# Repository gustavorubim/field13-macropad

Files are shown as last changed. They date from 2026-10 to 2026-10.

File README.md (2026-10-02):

# FIELD 13

An original, editable DIY macropad prototype with 13 MX hot-swap keys, a rotary encoder, a two-axis joystick, an optional touch position and a soldered Raspberry Pi Pico W.

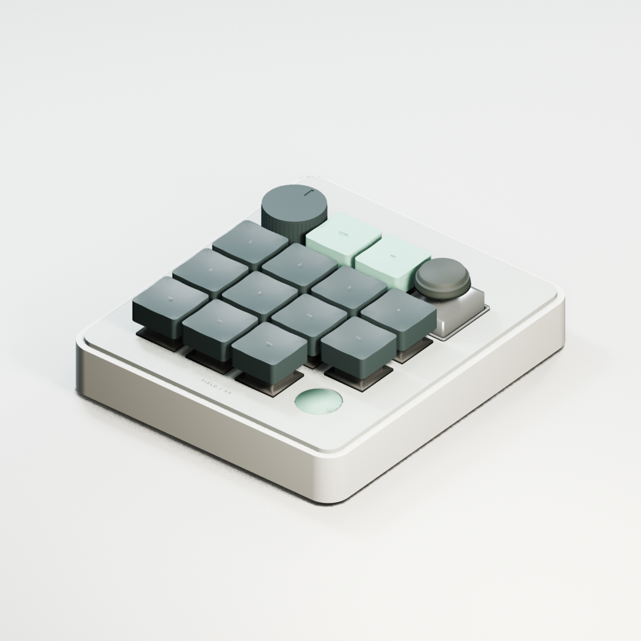
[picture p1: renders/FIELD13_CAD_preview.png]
FIELD 13 CAD assembly


**A0 design prototype. Not yet a fabrication release.** The files are real CAD, PCB and source code, but there has been no physical assembly, electrical bring-up, radio test or print-fit test. Software checks and CAD clearances cannot replace those tests.

## What is here

| Area | Deliverable |
|---|---|
| Electronics | Editable KiCad schematic, two-layer routed board, custom symbol/footprint libraries, source links and check reports |
| Mechanical | Native FreeCAD full assembly, STEP, printable case/plate/knob/feet, fit coupon and reproducible parameters |
| Visuals | Direct CAD preview, studio front/top/rear views, exploded view and editable Blender studio scene |
| Firmware | Code-configured keymaps/layers, encoder/media controls, joystick arrows/mouse, USB HID, optional authenticated Windows Wi-Fi companion |
| Integration | Optional Microbridge local serial companion for six agent focus keys and LED feedback; macOS daemon baseline |
| Build | Exact-part BOM, pin map, assembly instructions, bench tests and explicit remaining validation gates |

The layout follows the requested control arrangement: encoder and joystick around two top keys, two rows of four keys, and three bottom keys next to the optional touch position. All keycaps are standard 1U. The enclosure is 108 × 122 mm, with rounded corners, rear port access, underside fasteners and TPU feet.

## Start here

1. Read [the current verification status](docs/verification.md)
2. Inspect the KiCad project in `electronics/` and [electrical notes](docs/electronics.md)
3. Review [mechanical dimensions and print-fit gates](docs/mechanical.md)
4. Use the [BOM](docs/BOM.csv) and [assembly guide](docs/assembly.md)
5. Configure [firmware and host companions](docs/firmware.md)

## Editable sources

- `electronics/macropad.kicad_sch` and the final routed `.kicad_pcb` named in the electrical notes
- `mechanical/FIELD13_assembly.FCStd` and `FIELD13_assembly.step`
- `mechanical/parameters.json` plus `scripts/generate_mechanical.py`
- `mechanical/stl/` for printable parts, including the fit coupon
- `mechanical/FIELD13_studio.blend` plus `scripts/render_blender.py`
- `firmware/config.py` for keymaps, layers, encoder direction, joystick calibration and transport

The FreeCAD document has named editable solids, design-profile sketches and a dimension reference sheet. Regenerate changed dimensions from the JSON rather than assuming that changing the displayed sheet rebuilds the BRep solids. Purchased parts use documented clearance envelopes; not every small SMT detail is reproduced in CAD.

## Connectivity limits

USB HID is the default. Pico W Wi-Fi mode uses a separately started Windows companion and explicitly configured pairing key. It is not Bluetooth HID. CircuitPython's Pico W target does not provide CYW43 BLE HID in this build. No credentials are included, and no host service installs itself.

The optional Microbridge adapter is separate from the Windows Wi-Fi companion. It targets the pinned upstream protocol and only focuses/open assigned agent slots and receives status colors. It does not impersonate the commercial device's USB identity, approve actions, reject requests or synthesize unsupported daemon controls.

Power is USB or a finished external USB power bank. There is no bare lithium cell, charger or unprotected battery circuit. The microphone is a reserved connector/bay, not a tested microphone or USB-audio implementation. Optional touch/RGB peripherals require their own physical validation.

## Gallery

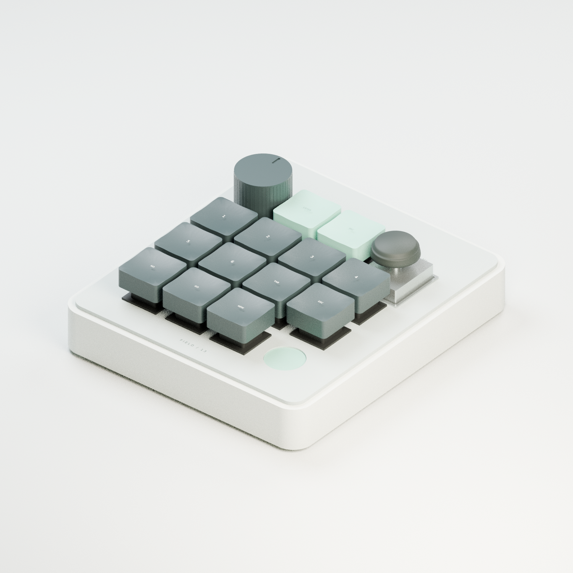
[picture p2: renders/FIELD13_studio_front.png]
Studio front

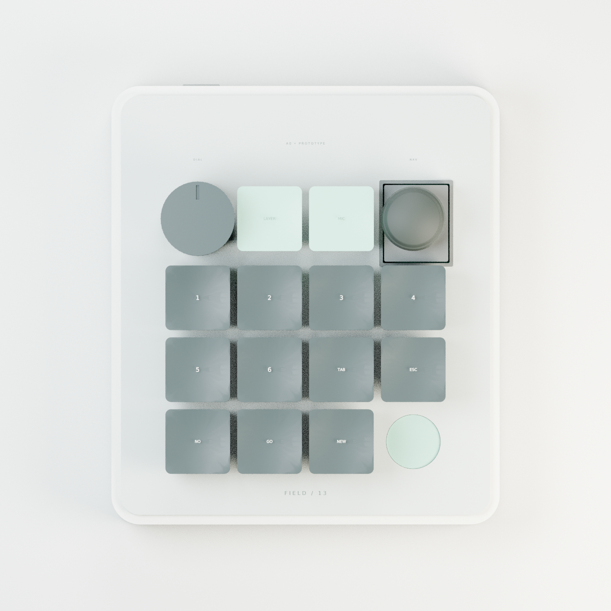
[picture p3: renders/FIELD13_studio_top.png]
Top view

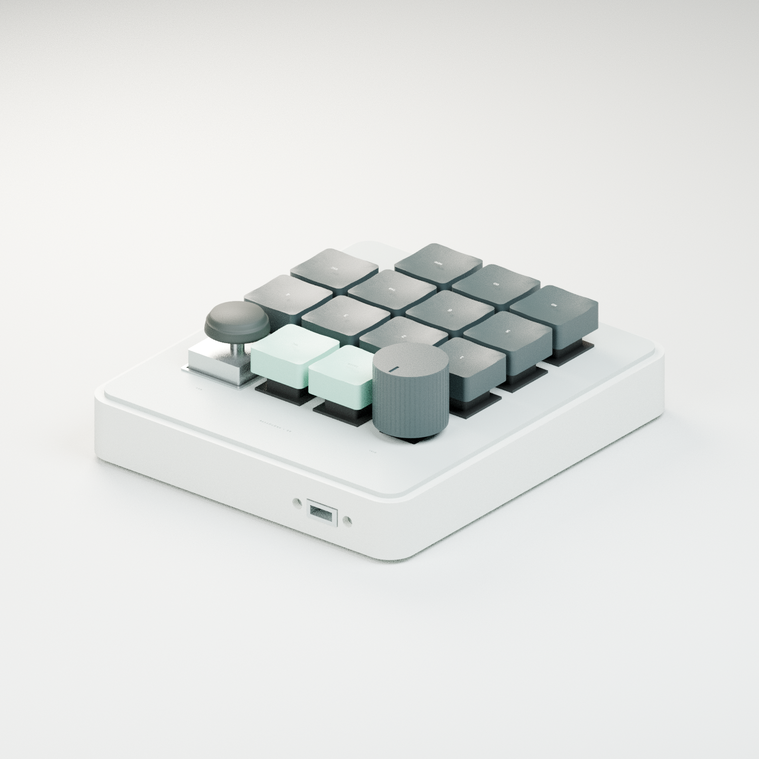
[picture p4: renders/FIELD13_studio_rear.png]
Rear view

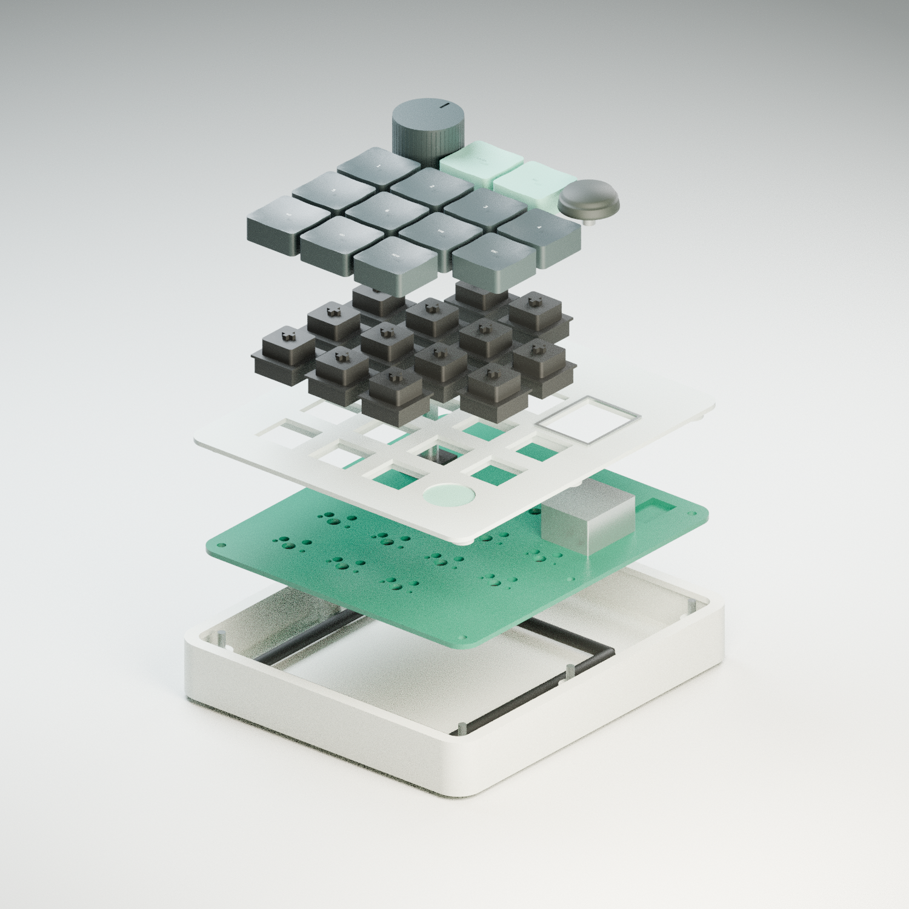
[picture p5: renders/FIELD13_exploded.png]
Exploded assembly


## Reproduce checks

```sh
python -m unittest discover -s tests/firmware -v
python -m compileall -q firmware
/usr/bin/python3 scripts/generate_mechanical.py
HOME=/tmp/macropad-home kicad-cli sch erc electronics/macropad.kicad_sch
```

The electrical notes identify the final PCB, final ERC/DRC commands and report files. Generated file paths are relative to this repository except where a tool requires its system library path. KiCad 9.0.2, FreeCAD 1.0 and Blender 4.3.2 were used in the development VM.

## Sources and credit

The requested arrangement was inspired by [OpenAI Supply Co. × Work Louder](https://openai.com/supply/co-lab/work-louder/). FIELD 13 is an independent DIY design, not an official product, clone firmware, compatibility certification or endorsement.

Component geometry and electrical constraints are based on the manufacturer sources linked in the BOM and electrical notes. Optional Microbridge interoperability is pinned to [DevVig/microbridge, fcd0aba](https://github.com/DevVig/microbridge/tree/fcd0aba7a4fa360ca8690681bd7b049fa3682f10). Third-party datasheets and external executable tools are not republished in this repository.

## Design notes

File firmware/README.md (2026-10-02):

# FIELD13 firmware prototype

Start with [the complete setup and verification guide](../docs/firmware.md).

- `boot.py`, `code.py`, `config.py`, `macropad/`: copy to CIRCUITPY
- `diagnostics.py`: optional non-HID hardware calibration tool
- `settings.example.toml`: placeholders only; Wi-Fi is opt-in
- `companion/wifi_companion.py`: Windows authenticated Wi-Fi HID, dry-run by default
- `companion/microbridge_companion.py`: macOS/Linux USB serial → local Microbridge v0, focus/LED only

USB is the default. No software or services are installed automatically. Real
CircuitPython, GPIO, USB enumeration, Windows input injection and radio operation
have **not** been tested on physical hardware. This is prototype source, not a
factory-ready binary or Bluetooth firmware.

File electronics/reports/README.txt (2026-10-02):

CANONICAL FINAL REPORTS: DRC.rpt and DRC.json (all severities plus schematic parity), ERC.rpt and ERC.json. All show zero violations. pcb_connectivity_check.json verifies 137 pin mappings against the electrical manifest. final_sha256.json binds these reports to the saved design. history/ contains superseded intermediate reports and is not the final status.

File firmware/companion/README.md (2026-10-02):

# Optional host companions

Both programs use Python 3's standard library and run in the foreground. Neither
is installed or started by this package. See `../../docs/firmware.md` for pairing,
security boundaries, firmware setup and full bring-up procedure.

## Windows wireless keyboard / mouse

```powershell
# Set ARC13_PSK privately in this process, identical to Pico settings.toml.
# Keep the whole firmware folder so the receiver imports the same config.py.
python firmware/companion/wifi_companion.py --bind 192.168.1.10 --device 192.168.1.20
# Inspect dry-run reports first. Only then explicitly enable OS input:
python firmware/companion/wifi_companion.py --bind 192.168.1.10 --device 192.168.1.20 --enable-input
```

Bind exact trusted-LAN IPv4s; reserve Pico DHCP address. Restrict inbound UDP
41413 to that device in the firewall yourself. Do not expose this port to the
Internet. Authenticated HMAC-SHA256 packets are **not encrypted**. No remote shell,
text command execution, arbitrary hotkey API, or Microbridge routing is provided.
Actual Windows SendInput operation is hardware/OS-untested.

## macOS Microbridge focus and LED mirror

```sh
python3 firmware/companion/microbridge_companion.py \
  --port /dev/cu.usbmodemYOUR_DATA_PORT \
  --socket "$HOME/.microbridge/microbridged.sock"
```

Choose the Pico's **data** CDC port, not its REPL console. No USB VID/PID scanning
or impersonation is used. On Linux the TTY commonly resembles `/dev/ttyACM1`,
but identify it rather than assuming an index. The local daemon must already be
installed and running; this package does not install it or change adapter consent.

Pin inspected: `DevVig/microbridge@fcd0aba7a4fa360ca8690681bd7b049fa3682f10`
(v0.3.10 formula commit). Exact sources:

- [Protocol](https://github.com/DevVig/microbridge/blob/fcd0aba7a4fa360ca8690681bd7b049fa3682f10/docs/protocol.md)
- [Rust message types](https://github.com/DevVig/microbridge/blob/fcd0aba7a4fa360ca8690681bd7b049fa3682f10/crates/mb-protocol/src/lib.rs)
- [Daemon handshake and subscribe implementation](https://github.com/DevVig/microbridge/blob/fcd0aba7a4fa360ca8690681bd7b049fa3682f10/crates/microbridged/src/socket.rs)

Only UI-role `hello` (protocol 0), `subscribe`, and `activate_agent_key` (indices
0–5, `open:true`) go to the daemon. Opening depends on the owning adapter's
`focus_open` capability. No `approve`, `reject`, interrupt, command passthrough,
or encoder injection is present. This is a narrow UI-protocol bridge, not an
upstream custom `Device` implementation and not the full Microbridge hardware.

`snapshot.agent_key_led_frame` and
`event.led_frame` (`kind=agent_keys_changed`) supply six static RGB colors.
Upstream percent brightness and pause are respected; the Pico adds its own local
power cap. Focus/breathing animations are not reproduced. Missing or incompatible
frames fail dark. The companion refreshes its snapshot every two seconds, treats
six seconds without a valid frame as stale, and sends LEDs every 0.5 seconds.
The Pico independently blacks out after two seconds without a valid LED message.

Fragmentation and **all** messages in a serial read are parsed. A bounded FIFO
preserves activation order at five per second, expiring queued input after two
seconds and socket write commands after 0.5 seconds. Disconnection discards
queued activations. This rate cap is intentionally for six agent focus buttons,
not a general keyboard input stream.

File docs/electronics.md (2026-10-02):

# FIELD 13 carrier electronics revision A

Engineering prototype, not a fabrication release. The supplied PCB is a real editable two-layer KiCad design with connected nets, routed copper, plated vias, manufacturer-derived footprints and an antenna cutout. Electrical and physical review gates are distinct: an ERC/DRC pass does not certify the new footprints, RF performance, USB budget, or printed assembly fit.

## Verification snapshot

The final KiCad 9 check includes all severities and schematic parity. `reports/DRC.rpt` and `DRC.json` report 0 violations, 0 unconnected pads and 0 footprint/parity errors under 0.20 mm trace/clearance and 0.50 mm edge rules. `reports/ERC.rpt` and `ERC.json` report 0 violations. The exported netlist was independently compared against all 137 electrical pin mappings. Physical review gates below remain open.

## Open and inspect

Open `electronics/macropad.kicad_pro` in KiCad 9. The main schematic is `macropad.kicad_sch`; the final PCB is `macropad.kicad_pcb`. Project-local symbol and footprint libraries are included. `net_manifest.json` gives the exact component/pin/net contract. `exports/` contains schematic SVG, PNG, PDF and native/XML netlists. `previews/` contains PCB top and mirrored-bottom SVG/PNG. `reports/` contains unfiltered KiCad checks and independent connectivity validation. Manufacturer sources are linked in the BOM; downloaded third-party datasheets are not republished in the repository.

Build scripts are editable. Do not run `build_pcb.py` over an edited PCB: it recreates placement and initial escape tracks; the full routing workflow is described below. The schematic generator also recreates its outputs.

## Geometry and assembly

- Case datum: rear is y=0, front y=122, width 108 mm
- Carrier: x 4..104, y 3.5..116, R6 corners, 1.6 mm thickness, PCB top Z 13.6 and bottom Z 12
- Six unplated Ø2.7 M2.5 clearance holes at (9,9), (99,9), (9,63), (99,63), (9,111), (99,111)
- Key centers: top (44,37),(64,37); rows x 24,44,64,84 at y 59 and 79; bottom x 24,44,64 at y 99
- Encoder shaft center (24,37); bare joystick shaft center (84,37)
- Optional vertical headers J1/J2/J3 are DNP and do not fit the closed case: their pin height exceeds the 3.6 mm PCB-to-plate gap. Use direct-solder insulated wire pigtails to the same pads for fitted options; validate strain relief and cable clearance
- Touch connector J1 runs horizontally from x 91 to 98.62 at y 94; it is a connector for an optional external module, not an onboard touch sensor
- RGB J2 at x 19..24.08,y 15; mic J3 at x 20..32.7,y 23; these and the encoder/joystick are front-side parts
- All 13 hot-swap sockets and diodes, Pico W, RGB buffer and passive parts are on the back
- Optional C2 is a 5.8 mm-tall underside part. It is DNP by default; do not assume the 4 mm socket clearance is sufficient for it

### Pico W mounting and RF

Pico W body outline is x 42..93,y 5..26. USB faces left, antenna right. Solder its castellations directly to carrier bottom pads with its components facing away from the carrier. No plug-in header stack is used. A real 14×9 mm carrier cutout is x 84..93,y 8.5..22.5. Copper rules prevent routing through the antenna window/end region. The underside interior beneath the module is also kept free of copper to avoid shorting exposed module testpoints. Four Ø2 mm unplated relief holes beneath USB shell solder joints reduce the risk of solder bulges holding the module off the carrier.

The rear board edge was extended 0.5 mm from y 4 to y 3.5, retaining R6 corners, to preserve a 0.5 mm copper-to-edge rule beneath the Pico pad row. Two vias near the antenna cutout were moved to y 7.68, with adjacent tracks rechecked.

A minimum mechanical no-metal volume of x 81..96,y 5.5..25.5 is reserved around the antenna. The module's own required castellated pads occupy the flanking rails; the carrier does not add a ground fill there. The right-rear nonmetallic printed boss has a 3.4 mm radius to support the heat-set insert. Its plastic enters the added 3 mm allowance by 0.4 mm; the brass insert (2.1 mm radius) and screw head (2.5 mm radius) stay outside the no-metal region. This nearby plastic is another reason RF performance must be measured. The enclosure is plain polymer near the antenna. This remains an interior-antenna arrangement; Raspberry Pi recommends board-edge placement. Measure wireless range with the final case and compare against a bare Pico W before accepting the arrangement. Avoid conductive filament, metalized paint, a battery, or bundled USB cable in this volume.

Raspberry Pi's datasheet explicitly specifies the 14×9 mm cutout and warns that nearby objects in any dimension reduce antenna effectiveness. The extra 3 mm margin is this prototype's engineering allowance, not a manufacturer guarantee. See the [Pico W datasheet](https://datasheets.raspberrypi.com/picow/pico-w-datasheet.pdf), mechanical section 2.2.1.

### Switch sockets

Kailh CPG151101S11-16 uses two Ø3 mm socket openings, 6.35 mm horizontal and 2.54 mm vertical separation. Custom pads are 2.55×2.5 mm at (-7.385,-2.54) and (6.115,-5.08) relative to key center. Stem hole Ø4 mm; optional five-pin switch locating holes Ø1.7 at x±5.08. Socket pads are on B.Cu. The pads were derived from the [manufacturer drawing](https://www.kailhswitch.com/Content/upload/pdf/202215927/CPG151101S11-16.pdf), matching the supplied earlier prototype reference. Print a footprint/plate coupon and physically insert the actual socket and switch before ordering a full carrier. No manufacturer's solderability or tolerance certification is claimed.

### Encoder

Chosen exact part is [ALPS EC11E15244B2](https://tech.alpsalpine.com/e/products/detail/EC11E15244B2/), 15 pulses, 30 detents, push travel 1.5 mm. Its current catalog uses Drawing 3. PCB mounting plane to tip is 24.5 mm, so the bare tip is Z 38.1 mm; the advertised 20 mm actuator dimension starts at the front of the 4.5 mm-thick encoder body. Shaft Ø6 with 4.5 mm flat dimension; the D-flat extends 10 mm down from the tip. Front body envelope is approximately 11.7×12 mm. The selected footprint is KiCad's EC11E vertical H20 switch footprint, with shaft center offset (7.5,2.5) from its pad-A origin. Verify its mounting tabs and slots against the purchased lot and current manufacturer drawing before fabrication.

### Joystick

Chosen exact part is [ALPS RKJXV1224005](https://tech.alpsalpine.com/e/products/detail/RKJXV1224005/), two 10 k linear pots and push switch. Its body is 17.8×21.3×11.2 mm; bare shaft reaches 18.95 mm above PCB, so tip Z 32.55. Boss projects 0.75 mm below its mounting plane, motion ±23°. The manufacturer's mounting-side diagram is saved next to the dimensional drawing. Pot terminals are at y=-8.73 with x=-2.5,0,2.5 and at x=8.73 with y=-2.5,0,2.5. Switch terminals are at x±4.3,y 0. Manufacturer-prohibited front-side wiring regions are covered conservatively by copper keepouts.

The F.Fab body outline uses approximately x−8.1..+9.7,y−9.4..+11.9 relative to shaft, interpreted from the manufacturer drawing scale. The 17.8×21.3 overall size is dimensioned, but these asymmetric shaft-to-body offsets are not independently dimensioned. They are explicitly provisional; the mechanical aperture includes extra allowance and requires a physical coupon.

This part is officially Not Recommended for New Designs. The exact part was offered by LCSC at the dated BOM check; availability can change. RKJXV122400R is not silently substituted: it has a different stated 18.2×21.7 mm envelope and must be reviewed as a distinct part. The custom joystick footprint, mounting tab drills, and shaft cap fit are first-article review gates.

## Electrical contract

| Function | Pico GPIO | Physical pins / notes |
|---|---|---|
| Rows 0..3 | GP0,1,2,3 | 1,2,4,5; drive one row low |
| Columns 0..3 | GP4,5,6,7 | 6,7,9,10; pull-up inputs |
| Encoder A/B/click | GP8,9,10 | 11,12,14; common and click return GND |
| Joystick click | GP11 | 15; active low |
| Optional touch SDA/SCL | GP12,13 | 16,17; I2C0; 3.3 V only |
| Optional six-pixel RGB | GP15 | 20; TTL-input AHCT buffer shifts to 5 V |
| Optional I²S BCLK/WS/DATA | GP16,17,18 | 21,22,24; reserved connector |
| Joystick X/Y | GP26,27 | 31,32; ADC0/1 |

The matrix positions are r0c1–r0c2; r1c0–r1c3; r2c0–r2c3; r3c0–r3c2. Each electrical path is COL → switch → diode anode → diode cathode → ROW. D1–D13 pin 1 is cathode. Firmware must scan columns with pull-ups while sinking one selected row. Never drive a column high against a selected low row through a pressed key.

Joystick pots are powered from 3V3, not 5 V. Direction and neutral deadband need calibration using the assembled joystick. Mechanical encoder contacts use GPIO pull-ups and firmware debounce; no 5 V signals go directly to Pico GPIO.

U2 is SN74AHCT1G125DBVR powered from USB 5 V, /OE grounded, with 100 nF bypass. Its input uses a 10 k pull-down, output a 330Ω series resistor. J2 pin 1=5V_USB,pin 2=RGB_DOUT,pin 3=GND. This is a low-speed pixel output, not a bidirectional 3.3 V expansion pin.

J1 pin 1=3V3,2=GND,3=SDA,4=SCL; optional 4.7 k pull-ups R1/R2 are DNP if a chosen module already supplies them. J3 pin 1=3V3,2=GND,3=BCLK,4=WS,5=DATA,6=GND. A microphone module must be a compatible 3.3 V I²S device; no microphone is fitted in this carrier revision.

## Power limits

The baseline is USB-only through the Pico W micro-B connector and the selected Adafruit 3258 panel extension. There is no lithium charging, protection, boost stage, battery connector, or battery firmware here. A finished external USB power bank may be used only as a 5 V USB source.

Do not allow six pixels at unrestricted full-white current. Start with all RGB off; target a conservative total pixel budget of 60 mA, then measure total USB draw with wireless transmitting and all options fitted. Confirm USB enumeration/descriptors and available host current. The optional 100 uF C2 is DNP until USB inrush is measured and accepted. Neither successful routing nor ERC measures power consumption or USB compliance.

## PCB manufacture and validation gates

The carrier uses two copper layers, nominal 0.25 mm signal routes, local 0.20 mm finished neckdowns, 0.20 mm clearance, 0.60 mm vias with 0.30 mm drills, and 0.50 mm copper-to-edge minimum. No ground pours were added; ground is explicitly routed. Confirm these limits with the intended fabricator and review current return paths, especially RGB current and ADC noise. This is a conservative first functional prototype, not an RF-optimized layout.

Before an order: read the final DRC report, inspect routed previews, confirm every custom footprint on a 1:1 print against physical parts, inspect the cutout and four USB relief holes, verify case ribs and component underside heights, and obtain a second PCB review. Before full assembly: print the mechanical fit coupon, test the matrix and controls on the bench, check supply polarity and USB draw, then assemble the case and repeat RF/joystick sweep tests.

## Reproducible routing

`build_pcb.py` uses system KiCad 9 pcbnew to create project footprints, placement, keepouts, and initial escapes, then writes Specctra `macropad.dsn`. The supplied routed PCB was made with official Freerouting 2.4.1 headless, followed by `finish_routes.py` to close two remaining connections against actual obstacles and KiCad DRC. Freerouting sources/release: https://github.com/freerouting/freerouting/releases/tag/v2.4.1 . The downloaded runtime is a temporary build tool, not included or installed on the user's computer.

The final PCB must be treated as authoritative. Re-running placement alone destroys its routing. The source scripts and final check reports preserve the reproducible design logic and verification evidence. Temporary `.dsn`, `.ses`, router executables and raw logs are excluded from the published repository; they are regenerated during a fresh routing run. Router-local 'violations' are not presented as KiCad results; the final KiCad report is the relevant geometric check. All reported physical manufacturing limits still require a first-article review.

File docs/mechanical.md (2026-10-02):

# FIELD 13 — mechanical prototype A0

The assembly is original and inspired by the reference control arrangement. It does not copy the original product's dimensions, industrial design files, marks, or electronics.

## Files and editability

- `mechanical/FIELD13_assembly.FCStd`: native FreeCAD document, individual named BRep solids, dimensions sheet, and separately editable design-profile sketches
- `mechanical/FIELD13_assembly.step`: complete neutral CAD assembly
- `mechanical/stl/`: printable parts and fit coupon, each shifted onto Z=0
- `mechanical/parameters.json`: the authoritative mechanical parameters; edit and run `/usr/bin/python3 scripts/generate_mechanical.py` to regenerate all manufacturing files
- `mechanical/FIELD13_studio.blend`: studio scene built from the same exported assembly geometry

The named BRep components can be inspected and modified with ordinary FreeCAD modeling tools. Changing the displayed dimensions sheet alone does not regenerate the BRep components; use the JSON and generator. Purchased-part geometry is a clearance envelope, not the manufacturer's full manufacturing model.

## Stack and fit

| Item | Dimension |
|---|---:|
| Case footprint | 108 × 122 mm |
| Outside corner radius | 8 mm |
| Base floor / nominal walls | 2.4 / 2.4 mm |
| Main PCB underside / top | 12.0 / 13.6 mm |
| Switch-plate underside / top | 17.2 / 18.7 mm |
| MX plate thickness at retention clips | 1.5 mm |
| PCB top → plate top | 5.1 mm |
| Key center pitch | 20 mm (top→middle 22 mm) |
| Initial switch cutout | 14.1 × 14.1 mm |
| Plate-to-case radial gap | 0.25 mm |
| Fasteners | six underside M2.5 screws |

The switch plate has reinforcement webs between rows and columns. Diodes and hot-swap sockets belong below the PCB. Push an MX switch fully into the plate before fitting its pins into a socket; support the socket from below during insertion. Hot-swap describes future switch replacement, not a solderless assembly process: every socket is soldered to the carrier PCB.

## Materials and first print

The user's stated GF-ABS, PETG and TPU options are retained; no printer or nozzle is assumed. Use GF-ABS or PETG for the rigid case, plain PETG for the RF-adjacent region and touch cover if necessary, and TPU for feet/joystick cap. Carbon-filled material is not treated as a substitute for glass-filled material near the antenna. RF behavior needs a real assembled test.

Print both the switch/shaft and control-aperture fit coupons first using the actual printer, nozzle and material. It includes 13.9/14.1/14.3 mm switch apertures and 6.0/6.2/6.4 mm shaft bores. The control coupon contains the encoder body opening and conservative joystick aperture. The joystick’s 17.8 × 21.3 mm overall body is manufacturer-documented, but its asymmetric offset about the shaft was estimated from the drawing; this requires a received-part fit test. Adjust clearances before a full print. Use the filament maker's temperature/drying settings; for abrasive filled materials, use the nozzle manufacturer’s suitable wear-resistant hardware. No slicer profile is certified here.

Base: floor on bed. Plate: flat upper surface down, bosses/ribs up; no supports inside switch openings. Knob: top on bed if the cosmetic surface permits. Feet: flat on bed in TPU. Check whether your slicer creates disconnected islands and rejects any non-manifold mesh before printing.

## Retention, wiring and service

The six mounts clamp the PCB between the base standoffs and upper plate bosses. Brass inserts are installed into the underside of the plate. Use the specified short insert variant; a longer insert can break through the visible face. Heat and hole fit must be calibrated with the actual plastic. The selected Accu SPP-M2.5-16-ST-BZP DIN 7985Z screw has a 5 mm maximum head diameter and 2.12 mm maximum head height. The 5.4 mm pocket is 1.7 mm deep, so the head may project 0.42 mm below the base, still above the 1.7 mm feet. Confirm this in a dry assembly before purchasing a full batch.

The rear port uses Adafruit 3258, a micro-B extension with 17.3 mm mounting-ear pitch. The port opening and body envelope still require measurement of the received cable. Its excess length routes in the floor corridor, secured by the two tie saddles, without loading the Pico USB connector. Do not substitute a power-only cable. The superficially convenient Adafruit 4056 USB-C adapter is deliberately not the baseline because its manufacturer warns of missing Type-C negotiation resistors.

Pico W is directly soldered to the underside carrier pads, with components facing the base. The antenna has the official 14 × 9 mm carrier cutout plus a larger no-copper/no-metal area. The module remains interior-mounted in this compact prototype. Antenna performance and interference are not established by a CAD check.

## Optional features

The touch position is a replaceable dielectric disc. The electrode/controller is optional and must be tested through the selected cover thickness. The optional vertical headers do not fit beneath the closed plate as drawn. Use direct-solder insulated wire pigtails at the same pads for a closed-case prototype; do not populate the listed vertical header variants without redesigning and measuring their mating clearance. The rear/front board connector reservations provide optional RGB and I²S microphone signals; they are not a claim of a working audio implementation. The microphone bay is reserved space only, hidden in finished renders.

## Release gates

This is a design prototype, not a fabrication release. Mechanical Boolean checks do not establish real fit, strength, switch feel, wear, cable bend radius, antenna performance or print shrinkage. Before ordering a PCB or printing the full case:

1. Confirm the selected controller, socket, switch, encoder and joystick drawings against the received parts
2. Print the fit coupon and adjust the parameter file
3. Verify the exact USB cable body, plug length and bend route
4. Verify the final KiCad board outline, drill positions and component envelopes in the FreeCAD assembly
5. Dry-fit the plate/PCB/fasteners, then test every switch socket with power disconnected
6. Perform the electrical bring-up and firmware checks in the assembly guide

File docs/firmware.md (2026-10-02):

# FIELD13 firmware and host setup

## What this prototype implements

**Wired:** standard USB keyboard, consumer/media keys and mouse using CircuitPython
on Raspberry Pi Pico W. No host companion is needed for USB shortcuts.

**Wireless:** opt-in 2.4 GHz Wi-Fi to a foreground Python companion on **Windows**.
The companion authenticates the device and injects only the configured key usages,
media actions and bounded mouse events. It defaults to dry-run. This is a host
software bridge, not Bluetooth HID and not a hardware wireless USB receiver.

**Optional Microbridge:** a separate macOS/Linux USB serial bridge mirrors six
agent LEDs and focuses/opens assigned agent slots through the local daemon's UI
socket. It has no approval/rejection action, no general encoder injection and no
full custom Microbridge Device implementation. Microbridge agent bindings are
rejected in Wi-Fi mode rather than silently doing nothing.

**Not implemented:** Pico W CYW43 Bluetooth/BLE support in this CircuitPython
firmware, microphone/audio processing, a component-specific I2C touch driver,
wireless Microbridge agent/LED routing, or a GUI configurator. I2C and microphone
pins are reserved for a future known module. The Pico W silicon having Bluetooth
capability does not make this program a Bluetooth keyboard.

All control logic is editable Python. Hardware has not been assembled or flashed
for these tests. Do the bring-up checklist before relying on macros.

## GPIO and key identity

| Function | Pico W GPIO | Notes |
|---|---|---|
| Matrix rows R0–R3 | GP0, GP1, GP2, GP3 | Diode cathodes/bands toward rows |
| Matrix columns C0–C3 | GP4, GP5, GP6, GP7 | Anodes toward columns; `columns_to_anodes=True` |
| Encoder A/B / click | GP8 / GP9 / GP10 | Click active-low to ground |
| Joystick click / X / Y | GP11 / GP26 / GP27 | 3.3 V analog supply only |
| Optional touch I2C SDA/SCL | GP12 / GP13 | Reserved; not initialized by runtime |
| Optional six-LED data | GP15 | Electrical level shifting/power per board guide |
| Reserved microphone | GP16 / GP17 / GP18 | No driver or assumed signal order |

Thirteen positions are numbered in visual reading order:

```text
            K00 (r0c1)   K01 (r0c2)
K02 (r1c0) K03 (r1c1)   K04 (r1c2) K05 (r1c3)
K06 (r2c0) K07 (r2c1)   K08 (r2c2) K09 (r2c3)
K10 (r3c0) K11 (r3c1)   K12 (r3c2)
```

The remaining matrix positions do nothing. Every switch needs its own correctly
oriented diode. Do not feed 5 V into a GPIO or ADC. Firmware cannot protect an
incorrectly wired power circuit; use the project's electrical guidance.

## Install on Pico W

1. Download the **Pico W**, not plain Pico, stable CircuitPython UF2 from the
   [official board page](https://circuitpython.org/board/raspberry_pi_pico_w/).
   The APIs used here target CircuitPython 9.x/10.x; use the current stable board
   build and its matching major-version library bundle. No UF2 is bundled.
2. Hold BOOTSEL while connecting USB, copy that UF2 to RPI-RP2, and wait for the
   CIRCUITPY drive. Follow the official board page if recovery is necessary.
3. Copy `firmware/boot.py`, `code.py`, `config.py`, and the complete `macropad/`
   directory to CIRCUITPY. Optionally copy `diagnostics.py`. Do **not** copy host
   `companion/`, tests or `__pycache__` directories onto the device.
4. From the official [CircuitPython library bundle](https://circuitpython.org/libraries),
   copy `adafruit_hid/` into CIRCUITPY/lib. For optional LEDs also copy `neopixel.mpy`.
   Dependencies are not downloaded or executed by this project.
5. Power-cycle. `boot.py` enables keyboard, mouse, consumer control, the REPL
   console CDC and a separate data CDC port. Descriptor changes require a real
   reset; editing `boot.py` alone does not update them. Keep the genuine
   CircuitPython VID/PID. Never use an ESPressif VID such as 0x303A.
6. Start with `TRANSPORT = "usb"`, `COMPANION_ENABLED = False` and
   `RGB_ENABLED = False`. Release every key and center the joystick for at least
   100 ms before input arms. The same rule applies after disconnect or overflow.

## Default behavior and editing

K00–K11 hold F13–F24; K12 is momentary Fn. F13–F24 are intended for application
shortcut assignment, though existing host mappings can already use them. Fn
provides copy, paste, cut, undo, redo, save, Home/End, Page Up/Down, Escape and Tab.
The encoder adjusts volume; its click mutes. With Fn held it scrolls. The joystick
holds arrow keys with diagonal combinations and clicks Enter.

`TARGET_OS = "windows"` selects Control shortcuts. Choose `macos` for Command.
The actual macro tuples live in `config.py`:

```python
from macropad.actions import keys, tap, momentary, toggle, mouse_button, consumer
LAYERS[0]["K00"] = keys("LEFT_CONTROL", "LEFT_SHIFT", "A")
LAYERS[0]["K01"] = tap("LEFT_CONTROL", "S")
LAYERS[0]["K12"] = momentary(1)
LAYERS[1]["K11"] = toggle(2)  # also create layer 2
LAYERS[0]["JOY_CLICK"] = mouse_button(1)
```

`keys` remains held until physical release; `tap` sends a short chord. Unspecified
layer entries are transparent. A release always uses the binding captured on
press, even if the layer changes. Shared modifiers are reference-counted. Use
canonical `adafruit_hid.keycode.Keycode` names, not multiple aliases for the same
usage. USB-compatible keyboard output is six ordinary keys plus modifiers.

`JOYSTICK_MODE` can be `arrows`, `mouse` or `disabled`. Calibration is explicit:
set minimum/center/maximum for each axis and change `inverted` if direction is
backward. Enter/leave thresholds default to 0.35/0.22 normalized travel, providing
hysteresis. No automatic boot centering assumes a held stick is centered. Stop
`code.py` with Ctrl-C in the REPL, then run `import diagnostics; diagnostics.run()`
to read raw ADC, matrix and encoder data without emitting HID. Ctrl-C releases
its GPIO objects. Set `ENCODER_DIVISOR` for the actual detent count; invert in
config if required.

## Windows Wi-Fi setup

1. Keep a matching copy of **the whole firmware directory** on the Windows host.
   Its `config.py` is also the receiver allowlist. After editing the Pico keymap,
   copy the same configuration to the host. Custom HID names may need an explicit
   entry in `macropad/hid_codes.py` and a Windows VK mapping.
2. On the device, copy `settings.example.toml` to `settings.toml` and privately
   enter your own Wi-Fi credentials, host IPv4 and random pairing secret. The
   placeholder is rejected. Generate a fresh 32-byte random secret locally, for
   example with `python -c "import secrets; print(secrets.token_hex(32))"`, and
   place that same value in the host process's `ARC13_PSK` environment variable.
   Do not commit secrets or put them in screenshots or support logs.
3. Use a trusted private WPA2/WPA3 LAN with a compatible 2.4 GHz SSID. Reserve the
   Pico's DHCP address. The firmware prints its assigned address at Wi-Fi startup.
   Restrict host UDP 41413 to that exact device IP yourself. No firewall, account,
   permission or startup-service settings are changed by these scripts.
4. Set `TRANSPORT = "wifi"`, leave Microbridge agent bindings disabled, and reboot.
   Wi-Fi connects only in this mode; USB-mode boot never waits for a network.
5. Start in dry-run, using your actual addresses:

   ```powershell
   python firmware/companion/wifi_companion.py --bind 192.168.1.10 --device 192.168.1.20
   ```

   Inspect report changes. With no keys held, the eight-byte keyboard report is
   all zeroes. Test disconnect, wrong PSK, and host restart before OS input.
6. Only after that, opt in to input:

   ```powershell
   python firmware/companion/wifi_companion.py --bind 192.168.1.10 --device 192.168.1.20 --enable-input
   ```

   The receiver uses Windows SendInput. Elevated applications can reject it due
   to Windows integrity isolation; do not disable security protections to force
   it. No macOS/Linux input injection is supplied. Dry-run is portable.

### Wireless safety and limitations

The wire protocol retains the legacy `ARC13/2` identifier and `ARC13_*` settings
names for compatibility; the hardware/project is FIELD13. It uses HMAC-SHA256 for reports **and handshake messages**, a
fresh host session nonce, monotonically increasing report sequence numbers, a
1,536-byte packet limit, and a configured key/media/button allowlist. It carries
full held-key snapshots and releases host-held keys/buttons after 0.5 seconds
without a valid report. That timeout rotates the session nonce, requiring the
Pico to release and re-arm. Host stop also releases input. It rejects general
commands and arbitrary text execution. Only one exact device IP is accepted.

HMAC authenticates data; it does **not encrypt** key reports or hide timing. This
is a local prototype protocol, not a security audit or an Internet-ready service.
A person with the pairing secret can generate the allowed inputs. Never use it
for passwords, security prompts or safety-critical controls. Disable keyboard
injection while debugging. No credentials are included in this repository.

UDP can lose or reorder packets. Held-state heartbeats arrive about every 50 ms;
short taps use redundant snapshots over about 50 ms. A lost short tap, media or
relative mouse event can still be missed; there is no guaranteed event delivery.
Wi-Fi latency is not gaming-grade. USB is the more reliable transport. On failed
initial Wi-Fi connection the runtime stops safely; correct settings and reset.
After a successful connection CircuitPython handles Wi-Fi reconnection, while
session checks keep remote input disarmed until a live companion returns.

## Optional Microbridge / six LEDs

Use USB mode and the matching local daemon on macOS (Unix socket transport also
works on Linux when a compatible daemon is available). It is **independent of the
Windows wireless companion**. Enable `COMPANION_ENABLED`, then deliberately map
six chosen switches to `agent(0)` through `agent(5)` using the commented example
in config. Enable `RGB_ENABLED` only after the external LED electrical interface
has been verified. The local NeoPixel brightness cap defaults to 15%, multiplied
by the daemon's brightness to limit power; do not treat this cap as power-circuit
protection.

Run the explicit data-port command in [companion/README.md](../firmware/companion/README.md).
The wire contract is pinned to Microbridge commit
`fcd0aba7a4fa360ca8690681bd7b049fa3682f10`. It only subscribes to resolved LED frames
and sends `activate_agent_key` for indices 0–5 with `open:true`. Opening requires
adapter support. No approvals, rejects, interrupts, synthetic encoder events,
upstream device impersonation, or third-party integrations are automatically
configured. No upstream software was installed or run during this build.

## Verification performed and remaining

Run from the project directory:

```sh
python -m unittest discover -s tests/firmware -v
python -m compileall -q firmware
```

At this build: **41 tests passed; 5 Unix-socket/PTY integration tests skipped**
because this cloud VM denies Unix socket creation, including after an escalation
attempt. The skipped tests remain runnable on a normal macOS/Linux machine.
Mock-transport tests cover handshake, six activations in one read, snapshot/event
batches, partial writes, stale queues, fail-dark and disconnection paths. Core
tests cover press/release ownership across layers, shared modifiers, debounce,
axis hysteresis, encoder batch preservation, input re-arming, JSON bounds and
LED validation. Wi-Fi tests cover an RFC 4231 HMAC vector, signed handshake,
wrong secret/session, replay/tampering, allowlist, timeout release/session renewal
and Windows usage mapping. Passing CPython tests does not validate GPIO timing,
CircuitPython compatibility on the actual board, or Windows SendInput behavior.

Before treating it as working hardware:

- Inspect diode polarity and 3.3 V joystick wiring before powering
- Run diagnostics: all 13 positions, both clicks, both encoder directions, ADC ranges
- Validate simultaneous switches, bounce, held modifiers and layer changes
- Unplug/replug USB while keys are held; confirm all keys release and require re-arming
- Check encoder divisor and joystick calibration on the actual parts
- Test all USB media and mouse actions in a disposable editor
- Dry-run Wi-Fi first, then test release on lost radio, host exit/restart and wrong PSK
- Verify Windows input and firewall scope on the intended host, with no sensitive apps open
- Test each Microbridge agent slot and LED, fragmented/batched serial input, daemon restart
- Confirm real LED current and logic levels before enabling its connector

## Primary references

- [Official Pico W CircuitPython download](https://circuitpython.org/board/raspberry_pi_pico_w/)
- [CircuitPython keypad polarity, debounce and queue semantics](https://docs.circuitpython.org/en/latest/shared-bindings/keypad/index.html)
- [CircuitPython rotaryio](https://docs.circuitpython.org/en/latest/shared-bindings/rotaryio/index.html)
- [CircuitPython USB CDC](https://docs.circuitpython.org/en/latest/shared-bindings/usb_cdc/index.html)
- [CircuitPython Wi-Fi API](https://docs.circuitpython.org/en/latest/shared-bindings/wifi/index.html)
- [Adafruit HID API](https://docs.circuitpython.org/projects/hid/en/latest/api.html)
- [Microsoft SendInput](https://learn.microsoft.com/en-us/windows/win32/api/winuser/nf-winuser-sendinput)
- [Microbridge pinned protocol](https://github.com/DevVig/microbridge/blob/fcd0aba7a4fa360ca8690681bd7b049fa3682f10/docs/protocol.md)

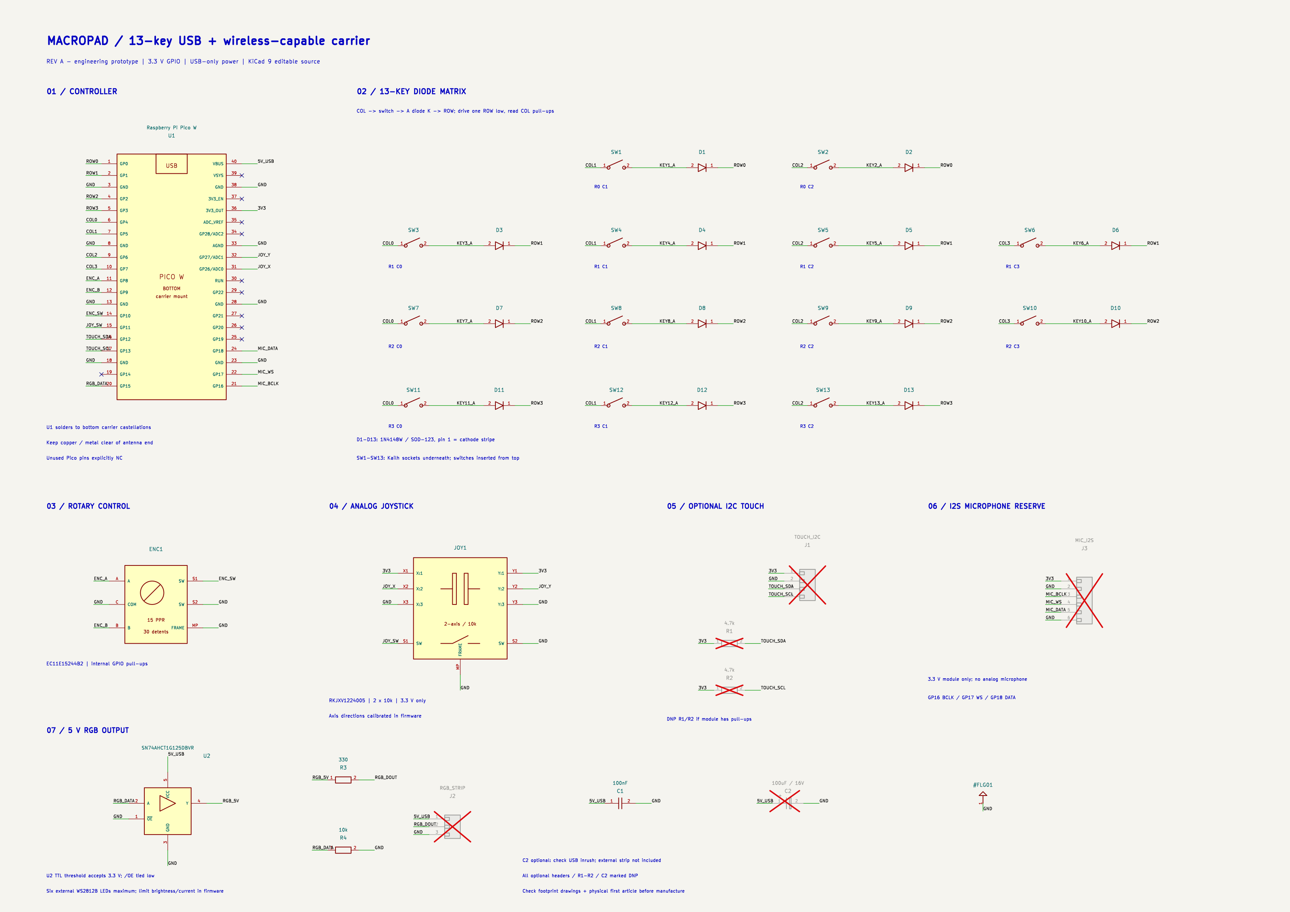
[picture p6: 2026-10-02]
electronics/exports/macropad.png

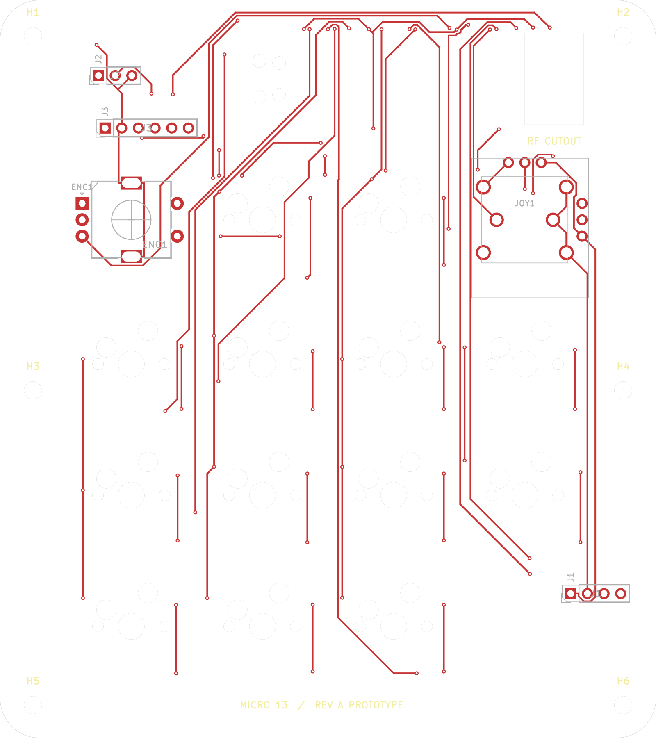
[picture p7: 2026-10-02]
electronics/previews/pcb-top.png

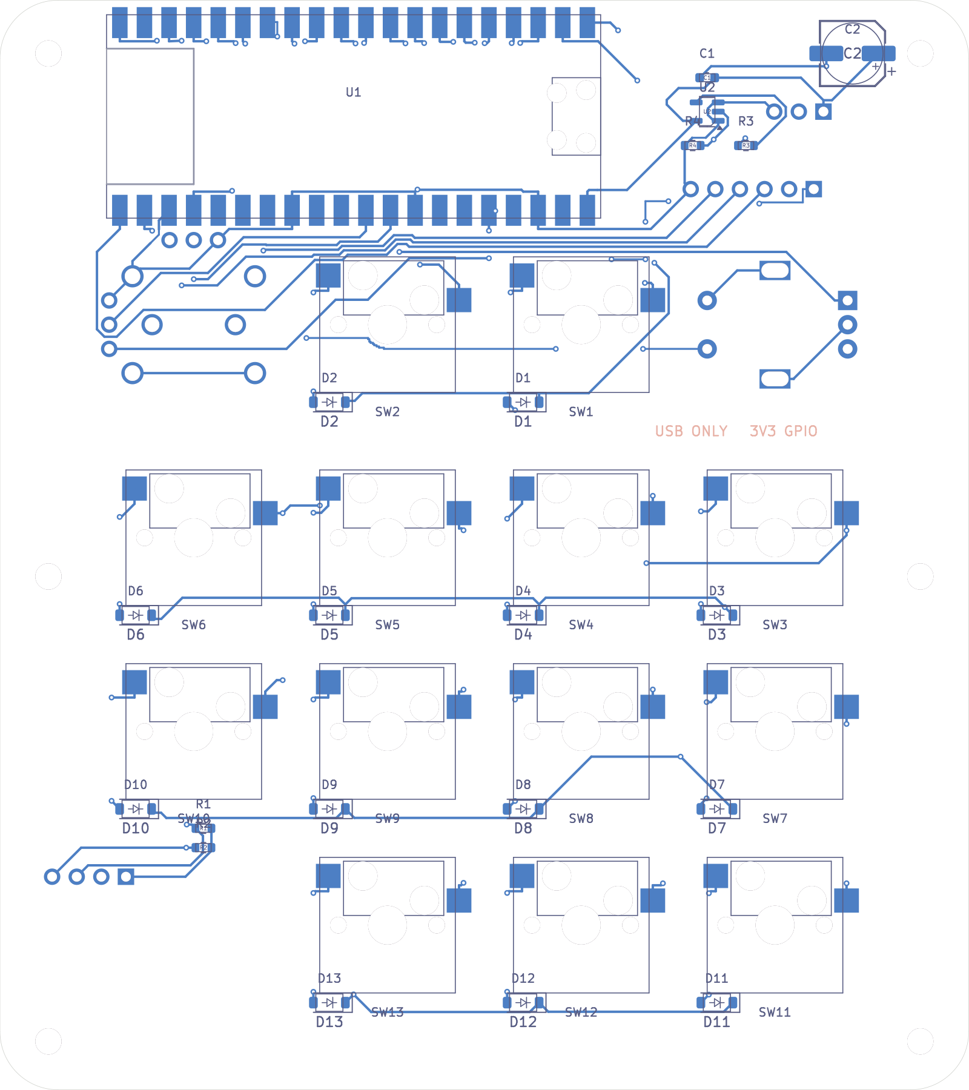
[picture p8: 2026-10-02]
electronics/previews/pcb-bottom.png

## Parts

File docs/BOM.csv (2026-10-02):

References | Quantity | Value | Manufacturer | Manufacturer part number | Footprint | Assembly | Manufacturer source URL | Vendor | Vendor SKU | Purchase URL | Order quantity | Pack contents | Observed unit price USD | Availability | Availability checked UTC | Availability evidence | Notes
U1 | 1 | Raspberry Pi Pico W | Raspberry Pi | SC0918 | Macropad:PicoW_Castellated | B | https://datasheets.raspberrypi.com/picow/pico-w-datasheet.pdf | DigiKey | 2648-SC0918CT-ND | https://www.digikey.com/en/products/detail/raspberry-pi/SC0918/16627943 | 1 | 1 Pico W | 6.00 | In stock: public page reports 7170 | 2026-10-02 | Public listing observed; stock and price may change. Shipping/tax/checkout not checked. | USB-powered Pico W; castellated carrier mount; USB connector faces left edge; antenna faces right
SW1-SW13 | 13 | MX hot-swap | Kailh | CPG151101S11-16 | Macropad:MX_Hotswap_CPG151101S11_16 | B | https://www.kailhswitch.com/Content/upload/pdf/202215927/CPG151101S11-16.pdf | LCSC | C5156480 | https://www.lcsc.com/product-detail/C5156480.html | 15 | Piece; minimum/multiple 5 |  | Unavailable: retailer says Not available now | 2026-10-02 | Public listing observed; stock and price may change. Shipping/tax/checkout not checked. | Socket on B.Cu; MX switch inserted from F.Cu; socket and switch are distinct BOM items; exact manufacturer MPN retained; LCSC source unavailable at check; see separately qualified Adafruit 4958 alternative
SW1-SW13 alternate supply | 13 | MX hot-swap | Kailh | CPG151101S11-16 designed; retailer MPN not stated | Macropad:MX_Hotswap_CPG151101S11_16 | Alternative source; confirm exact revision before order | https://cdn-shop.adafruit.com/product-files/4958/Datasheet.jpeg | Adafruit | 4958 | https://www.adafruit.com/product/4958 | 1 | 20 Kailh MX sockets; 13 used | 4.95 | In stock shown on public page | 2026-10-02 | Public listing observed; stock and price may change. Shipping/tax/checkout not checked. | Alternative supplier SKU, not an additional 13 sockets. Linked Kailh drawing matches 14.5x5.9x3mm body, 6.35mm contact separation and 2.54mm offset with 3mm pin holes; retailer does not state CPG part/revision. Confirm exact delivered revision before ordering/assembly.
D1-D13 | 13 | 1N4148W | Diodes Incorporated | 1N4148W-7-F | Diode_SMD:D_SOD-123 | B | https://www.diodes.com/assets/Datasheets/ds12019.pdf | DigiKey | 1N4148W-FDICT-ND | https://www.digikey.com/en/products/detail/diodes-incorporated/1N4148W-7-F/814371 | 13 | Cut tape individual diode |  | In stock: public listing reports 416216 | 2026-10-02 | Public listing observed; stock and price may change. Shipping/tax/checkout not checked. | Pin 1 cathode toward row; pin 2 anode toward switch
ENC1 | 1 | EC11E15244B2 | Alps Alpine | EC11E15244B2 | Rotary_Encoder:RotaryEncoder_Alps_EC11E-Switch_Vertical_H20mm | F | https://tech.alpsalpine.com/e/products/detail/EC11E15244B2/ | DigiKey | 4809-EC11E15244B2-ND | https://www.digikey.com/en/products/detail/alps-alpine/EC11E15244B2/19529170 | 1 | 1 encoder | 5.00 | In stock: public page reports 961 | 2026-10-02 | Public listing observed; stock and price may change. Shipping/tax/checkout not checked. | 30 detents / 15 pulses, 20 mm flat shaft, push switch
JOY1 | 1 | RKJXV1224005 | Alps Alpine | RKJXV1224005 | Macropad:Joystick_RKJXV1224005 | F | https://tech.alpsalpine.com/e/products/detail/RKJXV1224005/ | LCSC | C146170 | https://www.lcsc.com/product-detail/C146170.html | 1 | 1 joystick | 1.2054 | In stock: public page reports 2500; ships now | 2026-10-02 | Public listing observed; stock and price may change. Shipping/tax/checkout not checked. | Bare 2-axis 10k potentiometer joystick with click; custom logical pad names X/Y1..3 map to manufacturer potentiometer terminals 1..3; NRND; manufacturer NRND but exact SKU currently offered by LCSC; Mouser observed zero stock/backorder
J1 | 1 | TOUCH_I2C | Samtec | TSW-104-07-G-S | Connector_PinHeader_2.54mm:PinHeader_1x04_P2.54mm_Vertical | DNP / optional | https://www.samtec.com/products/tsw | DigiKey | 612-TSW-104-07-G-S-ND | https://www.digikey.com/en/products/detail/samtec-inc/TSW-104-07-G-S/1101323 | 1 | 1 four-position header | 0.38 | In stock: public page reports 6890 | 2026-10-02 | Public listing observed; stock and price may change. Shipping/tax/checkout not checked. | Optional 2.54 mm header; external peripherals not on PCB; CLOSED CASE: leave this header DNP/unfitted. Approximately 8.5mm vertical protrusion does not fit the 3.6mm PCB-to-plate gap. Baseline optional peripheral wiring uses direct-solder insulated pigtails to these same numbered pads; never claim standard headers fit this enclosure.
J2 | 1 | RGB_STRIP | Samtec | TSW-103-07-G-S | Connector_PinHeader_2.54mm:PinHeader_1x03_P2.54mm_Vertical | DNP / optional | https://www.samtec.com/products/tsw | DigiKey | 612-TSW-103-07-G-S-ND | https://www.digikey.com/en/products/detail/samtec-inc/TSW-103-07-G-S/1101324 | 1 | 1 three-position header | 0.27 | In stock: public page reports 32471 | 2026-10-02 | Public listing observed; stock and price may change. Shipping/tax/checkout not checked. | Optional 2.54 mm header; external peripherals not on PCB; CLOSED CASE: leave this header DNP/unfitted. Approximately 8.5mm vertical protrusion does not fit the 3.6mm PCB-to-plate gap. Baseline optional peripheral wiring uses direct-solder insulated pigtails to these same numbered pads; never claim standard headers fit this enclosure.
J3 | 1 | MIC_I2S | Samtec | TSW-106-07-G-S | Connector_PinHeader_2.54mm:PinHeader_1x06_P2.54mm_Vertical | DNP / optional | https://www.samtec.com/products/tsw | DigiKey | 612-TSW-106-07-G-S-ND | https://www.digikey.com/en/products/detail/samtec-inc/TSW-106-07-G-S/1101321 | 1 | 1 six-position header | 0.58 | In stock: public page reports 4477 | 2026-10-02 | Public listing observed; stock and price may change. Shipping/tax/checkout not checked. | Optional 2.54 mm header; external peripherals not on PCB; CLOSED CASE: leave this header DNP/unfitted. Approximately 8.5mm vertical protrusion does not fit the 3.6mm PCB-to-plate gap. Baseline optional peripheral wiring uses direct-solder insulated pigtails to these same numbered pads; never claim standard headers fit this enclosure.
R1,R2 | 2 | 4.7k | Yageo | RC0603FR-074K7L | Resistor_SMD:R_0603_1608Metric | DNP / optional | https://www.yageo.com/en/PartSearch | DigiKey | 311-4.70KHRCT-ND | https://www.digikey.com/en/products/detail/yageo/RC0603FR-074K7L/727212 | 2 | Cut tape individual resistor |  | In stock: public page reports 4356507 | 2026-10-02 | Public listing observed; stock and price may change. Shipping/tax/checkout not checked. | I2C pull-up: DNP if peripheral already fitted with pull-ups
R3 | 1 | 330 | Yageo | RC0603FR-07330RL | Resistor_SMD:R_0603_1608Metric | B | https://www.yageo.com/en/PartSearch | DigiKey | 311-330HRCT-ND | https://www.digikey.com/en/products/detail/yageo/RC0603FR-07330RL/727162 | 1 | Cut tape individual resistor |  | In stock: public page reports 282975 | 2026-10-02 | Public listing observed; stock and price may change. Shipping/tax/checkout not checked. | RGB data series damping resistor
U2 | 1 | SN74AHCT1G125DBVR | Texas Instruments | SN74AHCT1G125DBVR | Package_TO_SOT_SMD:SOT-23-5 | B | https://www.ti.com/lit/ds/symlink/sn74ahct1g125.pdf | DigiKey | 296-4708-1-ND | https://www.digikey.com/en/products/detail/texas-instruments/SN74AHCT1G125DBVR/376028 | 1 | Cut tape individual IC |  | In stock: public page reports 52420 | 2026-10-02 | Public listing observed; stock and price may change. Shipping/tax/checkout not checked. | 5V TTL-input buffer; 3.3V input accepted; /OE grounded
C1 | 1 | 100nF / 100V X7R | Murata | GRM188R72A104KA35D | Capacitor_SMD:C_0603_1608Metric | B | https://media.digikey.com/pdf/Data%20Sheets/Murata%20PDFs/GRM188R72A104KA35.pdf | DigiKey | 490-3285-1-ND | https://www.digikey.com/en/products/detail/murata-electronics/GRM188R72A104KA35D/702826 | 1 | Cut tape individual capacitor | 0.16 | In stock: public page reports 560991 | 2026-10-02 | Public listing observed; stock and price may change. Shipping/tax/checkout not checked. | 0603 X7R bypass adjacent to U2; stock-backed voltage-upgrade replacement for obsolete GRM188R71C104KA01D; same capacitance and PCB footprint
C2 | 1 | 100uF / 16V | Panasonic | EEE-FK1C101P | Capacitor_SMD:CP_Elec_6.3x5.8 | DNP / optional | https://industrial.panasonic.com/ww/products/pt/aluminum-cap-smd/models/EEEFK1C101P | DigiKey | PCE3783CT-ND | https://www.digikey.com/en/products/detail/panasonic-electronic-components/EEE-FK1C101P/766159 | 1 | Cut tape individual capacitor | 0.61 | In stock: public page reports 87070 | 2026-10-02 | Public listing observed; stock and price may change. Shipping/tax/checkout not checked. | Optional polarized bulk capacitor near RGB header; 6.3mm diameter x5.8mm nominal body (6.1mm maximum seated); same PCB footprint; validate USB inrush before populating; MECHANICAL: leave DNP unless the underside bay provides clearance for 5.8mm nominal / 6.1mm maximum seated height plus assembly tolerance. Verify bay against the physical capacitor before populating.
R4 | 1 | 10k | Yageo | RC0603FR-0710KL | Resistor_SMD:R_0603_1608Metric | B | https://www.yageo.com/en/PartSearch | DigiKey | 311-10.0KHRCT-ND | https://www.digikey.com/en/products/detail/yageo/RC0603FR-0710KL/726880 | 1 | Cut tape individual resistor | 0.10 | In stock: public page reports 4884 | 2026-10-02 | Public listing observed; stock and price may change. Shipping/tax/checkout not checked. | Pull-down holds AHCT input low during reset or high-impedance Pico GPIO state
External switches | 13 | MX-compatible switch | Cherry | MX2A-L1NN | Off-board removable | Required for use | https://www.cherry.de/en-gb/product/mx2a-red | DigiKey | 1644-MX2A-L1NN-ND | https://www.digikey.com/en/products/detail/cherry-americas-llc/MX2A-L1NN/21738390 | 13 | 1 Cherry MX2A Red switch | 1.75 | In stock: public page reports 237 | 2026-10-02 | Public listing observed; stock and price may change. Shipping/tax/checkout not checked. | Example linear switch; hot-swap socket footprint supports MX 3-pin/5-pin; confirm plate and cap compatibility
External LEDs | 6 | Mini Skinny NeoPixel RGB strip; six pixels used | Adafruit | 2963 | External strip / module | Optional | https://www.adafruit.com/product/2963 | Adafruit | 2963 | https://www.adafruit.com/product/2963 | 1 | 1 meter / 60 pixels; cut six-pixel section about 100mm | 14.95 | In stock: public page reports 14 strips | 2026-10-02 | Public listing observed; stock and price may change. Shipping/tax/checkout not checked. | Optional J2 external strip: buy 1m and cut six pixels (~100mm); 7.5mm wide x4mm with sleeve, 5mm bare width. May ship WS2812B or SK6812; 24-bit RGB protocol. Validate color order/timing; limit USB current in firmware. Do not power full 1m from Pico USB.
Keycaps | 13 | Black blank DSA 1U MX keycaps | Adafruit | 4997 | Off-board | Required for use | https://www.adafruit.com/product/4997 | Adafruit | 4997 | https://www.adafruit.com/product/4997 | 2 | 10 black DSA caps per pack; 20 total; 13 used | 5.95 | In stock: public page reports 4 packs | 2026-10-02 | Public listing observed; stock and price may change. Shipping/tax/checkout not checked. | Two 10-packs provide 20 caps; 13 used and seven spare. All keys 1U. DSA is standard-height MX profile, not low-profile CHOC.
Optional accent keycaps | 10 | Neon green blank DSA 1U MX keycaps | Adafruit | 5015 | Off-board | Optional cosmetic alternative | https://www.adafruit.com/product/5015 | Adafruit | 5015 | https://www.adafruit.com/product/5015 | 1 | 10 neon-green DSA caps per pack | 5.95 | In stock: public page reports 69 packs | 2026-10-02 | Public listing observed; stock and price may change. Shipping/tax/checkout not checked. | Optional accent pack; replaces selected black caps, does not add keys
USB extension | 1 | Micro-B male to panel-mount micro-B female extension | Adafruit | 3258 | Panel mount / cable | Required | https://www.adafruit.com/product/3258 | Adafruit | 3258 | https://www.adafruit.com/product/3258 | 1 | 1 cable; includes two M3 x12 panel screws | 4.95 | In stock shown on public page | 2026-10-02 | Public listing observed; stock and price may change. Shipping/tax/checkout not checked. | 17.3mm panel screw pitch;30cm cable; reserve slack corridor; supplier drawing fit check
Case inserts | 6 | M2.5 D4.2 L3 brass heat-set insert | Trianglelab | M2.5 D4.2 L3 option | Printed-case bosses | Required | https://www.trianglelab.net/products/trianglelab-hot-melt-insert-nuts-m25-m3-m4-m5-m6-brass-nuts | Trianglelab | M2.5 D4.2 L3 option | https://www.trianglelab.net/products/trianglelab-hot-melt-insert-nuts-m25-m3-m4-m5-m6-brass-nuts | 6 | Confirm pack quantity / exact option on retailer page |  | Stock unverified: exact variant or dynamic availability not reliably exposed | 2026-10-02 | Public product page read 2026-10-02; no reliable exact-variant stock confirmation | CAD pilot3.8mm depth3.3mm; print-fit coupon required
Case screws | 6 | M2.5 x16 DIN7985Z Pozi panhead | Accu | SPP-M2.5-16-ST-BZP | Underside assembly | Required | https://www.accu.co.uk/pozi-pan-head-screws/500109-SPP-M2-5-16-ST-BZP | Accu | SPP-M2.5-16-ST-BZP | https://www.accu.co.uk/pozi-pan-head-screws/500109-SPP-M2-5-16-ST-BZP | 6 | Confirm pack quantity / exact option on retailer page |  | Stock unverified: exact variant or dynamic availability not reliably exposed | 2026-10-02 | Public product page read 2026-10-02; no reliable exact-variant stock confirmation | HeadØ5mm max,height2.12mm max. CAD pocketØ5.4x1.7deep;0.42mm head projection protected by1.7mmfeet
Printed case set | 1 | Base plate knob joystick cap touch blank | Project | Revision A | See mechanical sources | Required |  |  |  |  |  |  |  | Generated prototype |  | Project-generated parts; print after fit validation | Dimensions require physical fit coupon; no purchased generic knob substituted

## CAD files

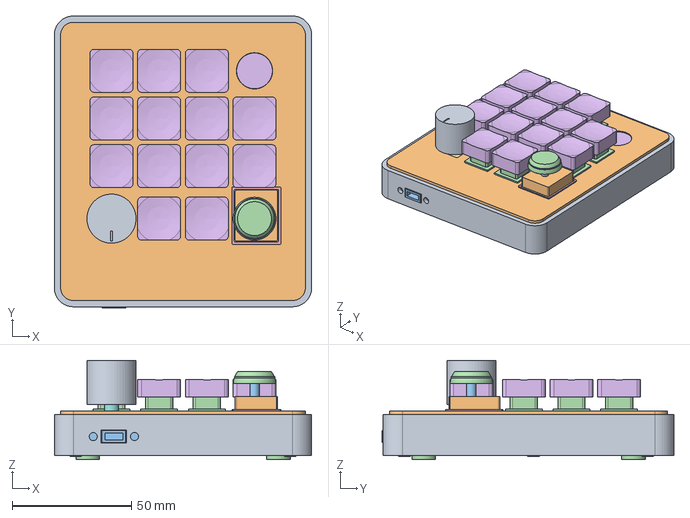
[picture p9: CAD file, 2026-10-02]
mechanical/FIELD13_assembly.step
108.0 x 122.5 x 41.7 mm

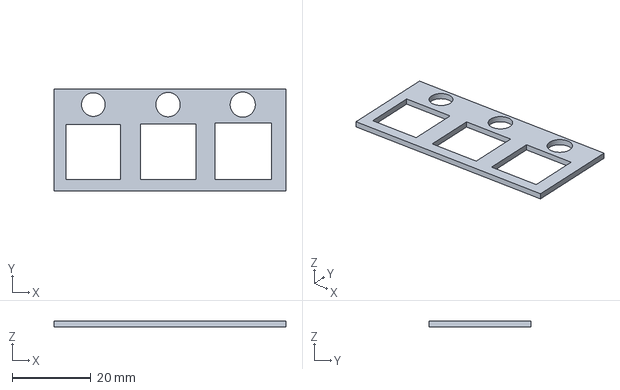
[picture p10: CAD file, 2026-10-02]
mechanical/Fit_coupon.step
59.0 x 26.0 x 1.50 mm

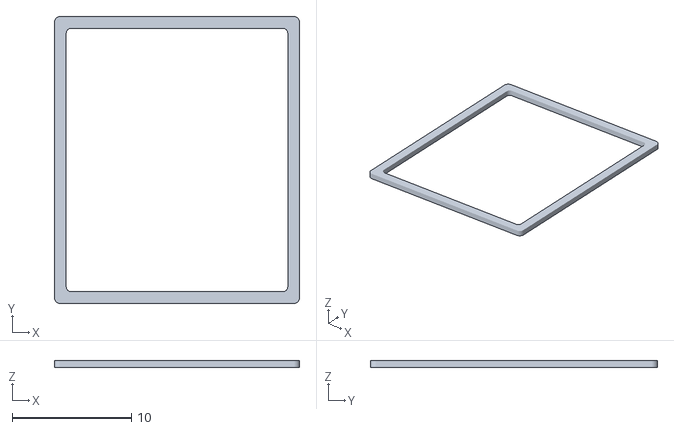
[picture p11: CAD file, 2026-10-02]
mechanical/stl/Joystick_bezel.stl
20.6 x 24.1 x 0.6

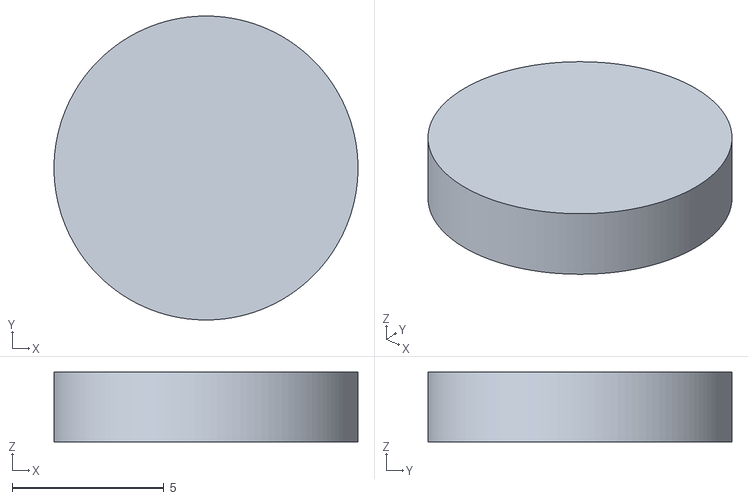
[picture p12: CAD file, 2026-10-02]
mechanical/stl/Foot_02_TPU.stl
10.0 x 10.00 x 2.30

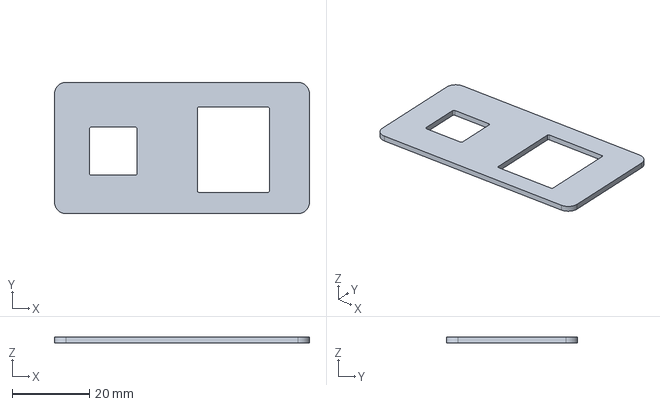
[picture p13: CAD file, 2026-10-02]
mechanical/Control_fit_coupon.step
66.0 x 34.0 x 1.50 mm

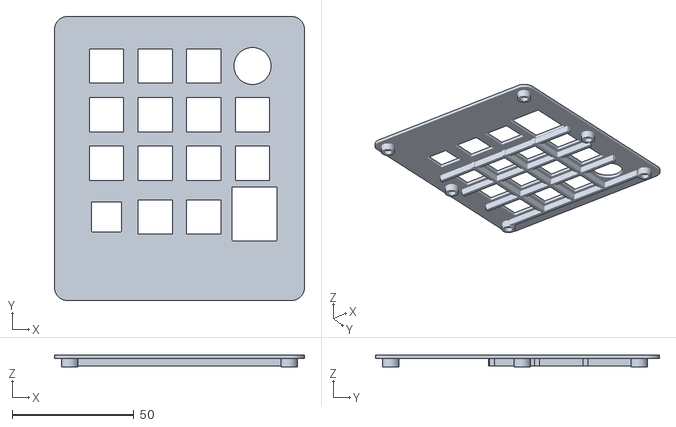
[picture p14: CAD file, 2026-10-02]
mechanical/stl/_3_Switch_plate.stl
102.7 x 116.7 x 4.90

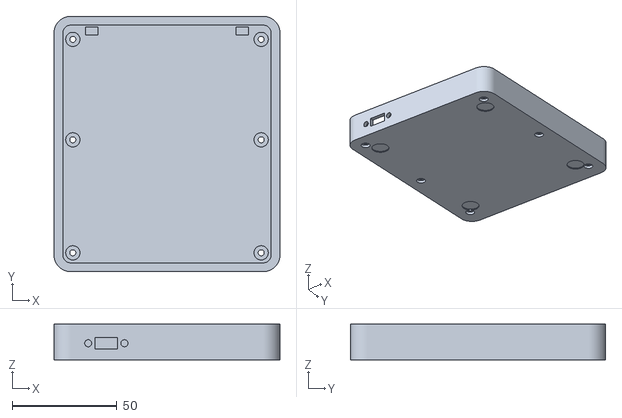
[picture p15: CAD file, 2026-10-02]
mechanical/stl/_1_Base_shell.stl
108.0 x 122.0 x 17.2

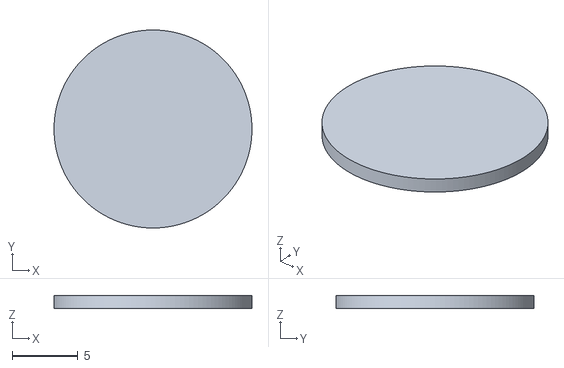
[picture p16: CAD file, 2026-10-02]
mechanical/stl/Touch_cap_PETG.stl
15.0 x 15.0 x 1.00

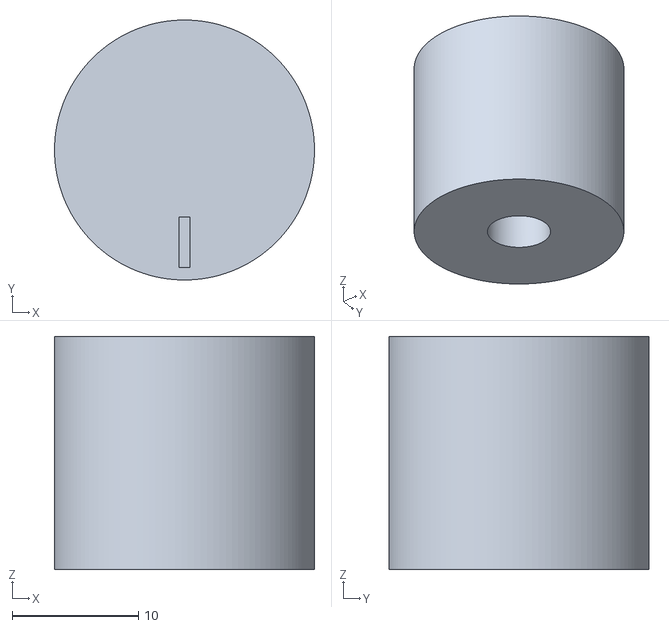
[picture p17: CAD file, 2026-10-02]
mechanical/stl/Encoder_knob.stl
20.6 x 20.6 x 18.5

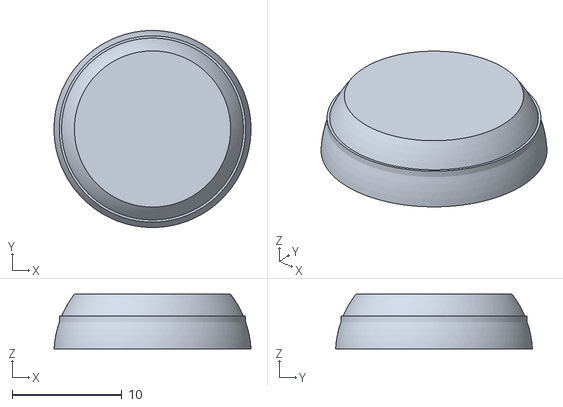
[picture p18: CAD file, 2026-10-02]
mechanical/stl/Joystick_cap_TPU.stl
18.0 x 18.0 x 5.00

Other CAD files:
mechanical/stl/Foot_03_TPU.stl
mechanical/stl/Foot_04_TPU.stl
mechanical/stl/Foot_01_TPU.stl
mechanical/FIELD13_assembly.FCStd
mechanical/FIELD13_exploded.blend
mechanical/FIELD13_studio.blend
mechanical/stl/Control_fit_coupon.stl
mechanical/stl/Fit_coupon.stl

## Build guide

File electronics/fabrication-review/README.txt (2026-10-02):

REVIEW EXPORTS ONLY - NOT APPROVED FOR FABRICATION

These Gerbers and drills are exported from the actual routed KiCad carrier.
Before manufacturing, verify the latest DRC.rpt and all physical review gates
in docs/electronics.md. KiCad clearance/connectivity checks do not certify
footprint dimensions, component availability, mechanical fit, RF performance,
USB power/inrush or safety compliance. Custom footprint first-article review
and a second engineer's PCB review remain required.

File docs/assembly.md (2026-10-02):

# FIELD 13 assembly and bench test guide

This guide is for a competent hobbyist building the A0 prototype. Read the verification report first. Do not order boards until the selected parts, PCB footprint orientation and remaining release gates have been reviewed. No physical build has been completed from these files.

## 1 Check the parts and print coupon

Confirm every manufacturer part number against the BOM. A hot-swap socket is not a switch: 13 sockets, 13 MX-compatible switches and 13 keycaps are separate items. Do not substitute Kailh Choc sockets for the specified MX socket.

Open the native FreeCAD assembly and final KiCad PCB. Compare the mounting-hole centers and outline. Print the fit coupon with the intended material/nozzle. Test one switch, one keycap and the selected encoder shaft before printing the complete plate. Adjust the JSON clearances if needed and regenerate all CAD exports together. Check the USB extension’s actual body and screw ears against the panel opening.

The user's printer/nozzle is not fixed by this design. The rigid parts may be GF-ABS or PETG after calibration; feet and joystick cap use TPU. Use a suitable wear-resistant nozzle for abrasive filled filament according to its manufacturer. Dry and print the material according to the filament maker's guidance.

## 2 Prepare the PCB without power

Use eye protection, ventilation/fume extraction and a stable heat-resistant work surface. Disconnect USB and every power source while soldering or inserting/removing switches. Work in an ESD-conscious setup.

1. Inspect the bare board against the final Gerber/PCB view. Confirm the antenna cutout, four USB-shell relief holes, switch holes and all mounting holes
2. Solder the small bottom-side resistors, capacitors and diodes. Diode cathode bands face the matrix row nets; verify against the actual silkscreen and schematic, not a photo alone
3. Solder the 5 V AHCT RGB buffer and its decoupling/pull-down if populating that circuit. Leave optional connectors and bulk capacitor unpopulated for the first bring-up. For later closed-case use, direct-solder insulated wire pigtails at the optional connector pads; the listed standard vertical headers would collide with the plate
4. Align and solder all 13 bottom-side hot-swap sockets. Inspect both pads of every socket and check that the spring contacts are unobstructed
5. Test-fit the Pico W on the underside in the orientation shown by KiCad. Components face away from the carrier. Confirm its USB connector shell solder blobs clear the relief holes and its antenna sits above the carrier cutout. Tack opposite pads, verify flush alignment, then finish soldering
6. Solder the encoder and joystick on the top. Confirm joystick X/Y wipers and common rails against the manufacturer drawing. The potentiometers use 3.3 V, never 5 V
7. Clean flux where appropriate and inspect with magnification. Check for bridges and unintended shorts before fitting any case or keycaps

Do not mount a bare lithium battery or charging circuit. The board is designed for USB or a finished external USB power bank only.

## 3 Electrical checks before USB

With no power connected, inspect/measure:

- No metallic debris, lifted pads, solder bridges or reversed diodes
- GND continuity to the intended ground pads and connector shell where specified
- No hard short between VBUS and GND, or 3.3 V and GND; allow meter readings to settle as capacitors charge
- Each switch closes only its intended row/column path through the diode
- Joystick resistance changes smoothly; wipers are not shorted to the supply rails
- Optional RGB and microphone pins match the connector legends and electrical notes

Use the schematic and actual component datasheets to interpret readings. Do not infer a safe power connection solely from a continuity beep. If any reading is ambiguous, stop and find the cause.

## 4 First power and firmware

Use a protected, current-limited USB source or an appropriate USB current monitor for initial bring-up. Keep the board outside the enclosure on an insulating surface. Stop and disconnect if it heats unexpectedly, draws abnormal current or fails to enumerate.

Flash the official CircuitPython build for Raspberry Pi Pico W, then follow [firmware setup](firmware.md), including the required Adafruit HID library. Use diagnostics before the HID application when possible. Leave Wi-Fi, external LEDs and companion integration disabled.

Record the following in a local build log:

| Test | Expected observation | Result |
|---|---|---|
| Power rails | Stable USB input and 3.3 V rail within component limits | Not run |
| Matrix | Exactly 13 intended positions, no phantom keys | Not run |
| Multi-key | Concurrent presses/releases preserve independent keys | Not run |
| Encoder | Correct direction and one desired action per detent after calibration | Not run |
| Encoder click | Press and release register once, no stuck action | Not run |
| Joystick click | Press and release register correctly | Not run |
| Joystick axes | Center, endpoints and polarity calibrated in config | Not run |
| Layer hold | Held actions release correctly while changing layers | Not run |
| USB reconnect | No stuck keys after removal/reconnect | Not run |

Use a disposable text editor for initial HID tests. Default F13–F24 bindings are intended to be configured by the user; the cosmetic render legends are not a guarantee of a particular app’s shortcuts. Avoid destructive shortcuts during bring-up.

## 5 Assemble the enclosure

1. Install the six short M2.5 heat-set inserts into the underside of the plate. Heat and pilot fit depend on the actual plastic. Keep the insert axes square; do not press through the top face
2. Fit the optional touch cover or leave the area unpopulated as described in the mechanical notes
3. Fit switches into the plate and check that both retention clips engage. Keep switch pins straight. Support hot-swap sockets from below while marrying the plate/switch assembly to the PCB
4. Fit the panel USB extension. Route its slack in the reserved floor corridor and secure it with the tie saddles. Nothing should press on the Pico antenna, joystick pins or bottom-side components
5. Place the PCB on the base standoffs. Confirm the upper plate bosses land above the mounting holes and the reinforcement webs miss the components
6. Insert the six underside M2.5 × 16 mm fasteners. Tighten gently and evenly; excessive torque can damage printed bosses or flex the PCB
7. Fit the encoder knob, joystick cap, keycaps and TPU feet. Confirm full key travel, encoder push travel and joystick travel in every direction without rubbing
8. Re-run the complete wired test sequence after closing the case

The screw head pockets permit a small head projection below the base; the TPU feet provide clearance. Confirm the actual head does not touch the desk. Check that the screw tip does not break through the upper face.

## 6 Optional wireless and agent feedback

Configure Wi-Fi only after wired bring-up succeeds. The Windows companion starts in dry-run mode. Set a unique pairing secret locally and never commit the actual settings file. Restrict the host firewall to the intended private network/device; firewall changes are an explicit user setup step. Test wrong-secret, replay, signal loss, host shutdown and reconnect behavior before enabling real input. Wi-Fi control traffic is authenticated but not a substitute for a trusted network.

Microbridge integration uses a separate USB serial data channel and the pinned local daemon protocol. It supports six focus/open slots and LED feedback, with stale frames failing dark. Test it on the intended macOS host; it is not the Windows wireless HID transport. External LEDs require a verified 5 V/current budget and the level-shifted data interface. Do not power a large strip from an unverified USB source.

Touch sensing and microphone audio are optional follow-on validation items. The microphone bay and I²S pins reserve space and signals only. No claim is made for USB microphone enumeration, audio quality or push-to-talk behavior.

## 7 Before a second board revision

Record mechanical interference, RF behavior with the chosen case material, power consumption, key feel and any fixes to the firmware calibration. Update the board, CAD and parameter source together; re-run ERC, DRC, firmware tests and all critical collision checks. Keep the failed prototype files or photos as evidence rather than silently declaring the first revision production-ready.

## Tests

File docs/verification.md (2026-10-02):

# FIELD 13 verification status

**A0 is a design prototype. Hardware and fabrication release are not validated.** This file separates checks performed on generated files from tests requiring physical components.

## Completed checks

- Native FreeCAD assembly generated and reopened successfully; 73 individual part solids valid
- 42 specified component/structure Boolean overlap and stack checks passed in `mechanical/validation.json`
- Main shell/PCB/plate have no volumetric overlap in the evaluated assembly
- Exact 13-key count, 1.5 mm MX retention plate and 5.1 mm PCB-top-to-plate-top stack verified
- Independent KiCad ERC and DRC reruns passed with 0 violations, 0 unconnected pads and 0 schematic parity errors; all severities enabled, 0.20 mm minimum track/clearance and 0.50 mm minimum copper-to-edge rule
- CAD-to-PCB alignment checked: all 13 switch centers, all 6 mounts and the final board envelope match; see `mechanical/cad_pcb_alignment.json`
- Schematic XML connectivity comparison covered 137 pins and 39 components, with 0 mismatches at the recorded checkpoint
- Firmware: 41 CPython tests passed, 5 real Unix-socket/PTY integration tests skipped because the VM disallows Unix socket creation; see `docs/firmware.md`
- Direct CAD rendering checked visually before delivery; cosmetic legends/colors are design choices, not populated hardware features

## Not validated by those checks

Physical hot-swap contact fit, pad durability, print shrinkage/warping, insert retention, screw torque, USB cable body/bend radius, joystick full travel under real loads, electrical current consumption, board bring-up, USB descriptors on real hardware, Windows input injection, actual radio connectivity, RF performance, external LED current, capacitive sensing and microphone audio.

The FreeCAD assembly includes documented envelopes for purchased parts. It does not substitute for importing every manufacturer STEP model or measuring received parts. The fit coupon and physical checks in the assembly guide are required before treating the enclosure as print-ready for a particular printer/material combination.

No physical tests or fabrication approval are implied by an empty ERC/DRC report. Do not order a production quantity from this prototype without an independent review and successful first article.

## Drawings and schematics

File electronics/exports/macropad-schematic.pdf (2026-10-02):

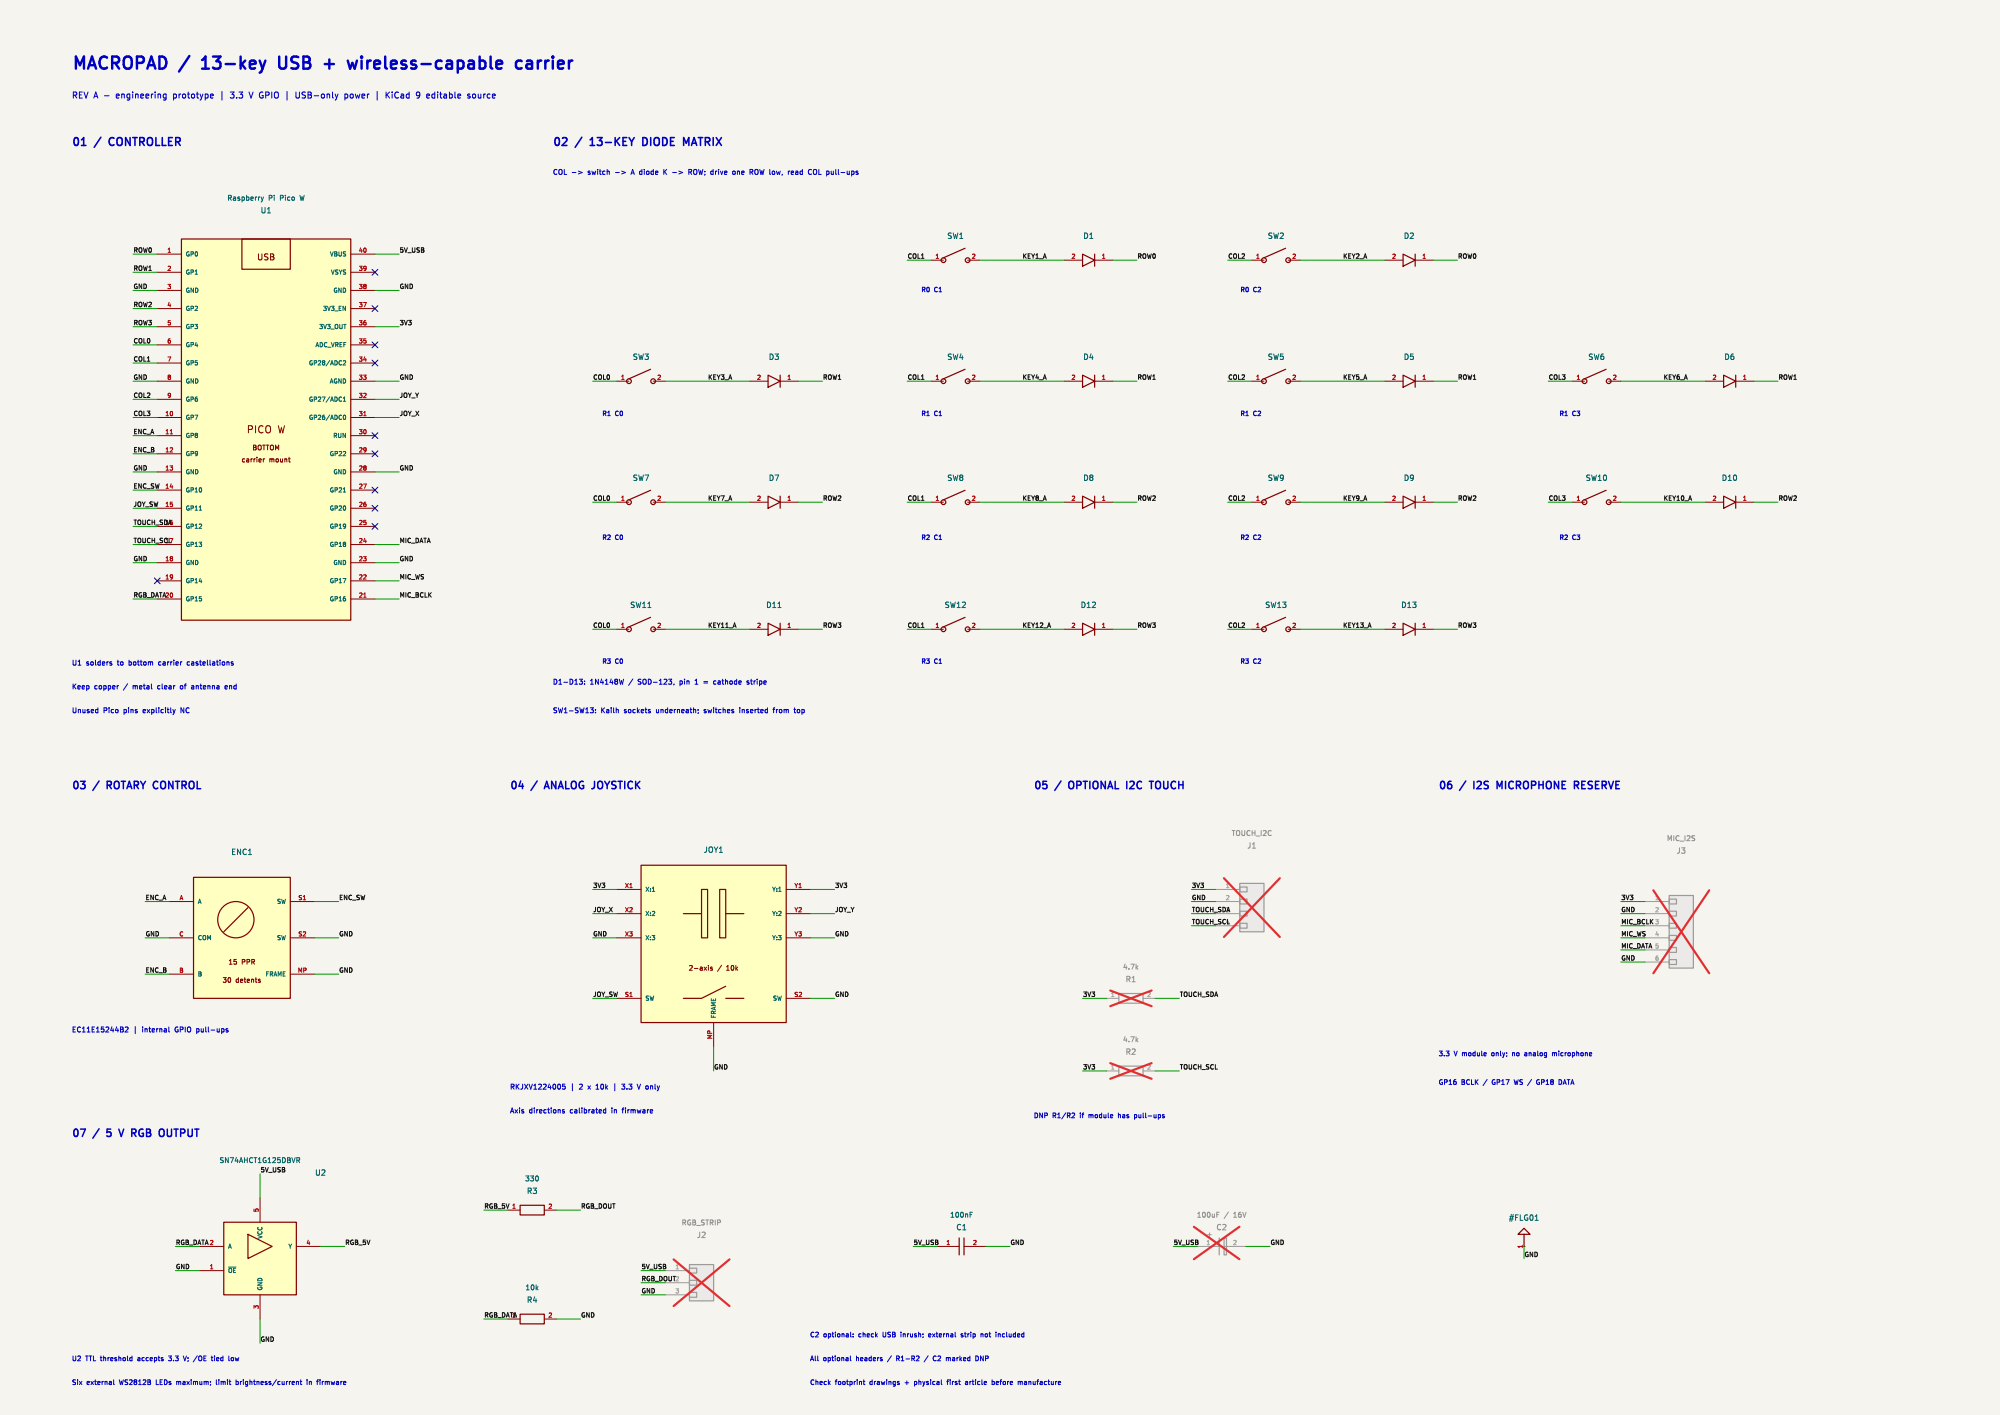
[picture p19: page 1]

Keep copper / metal clear of antenna end

3.3 V module only; no analog microphone GP16 BCLK / GP17 WS / GP18 DATA

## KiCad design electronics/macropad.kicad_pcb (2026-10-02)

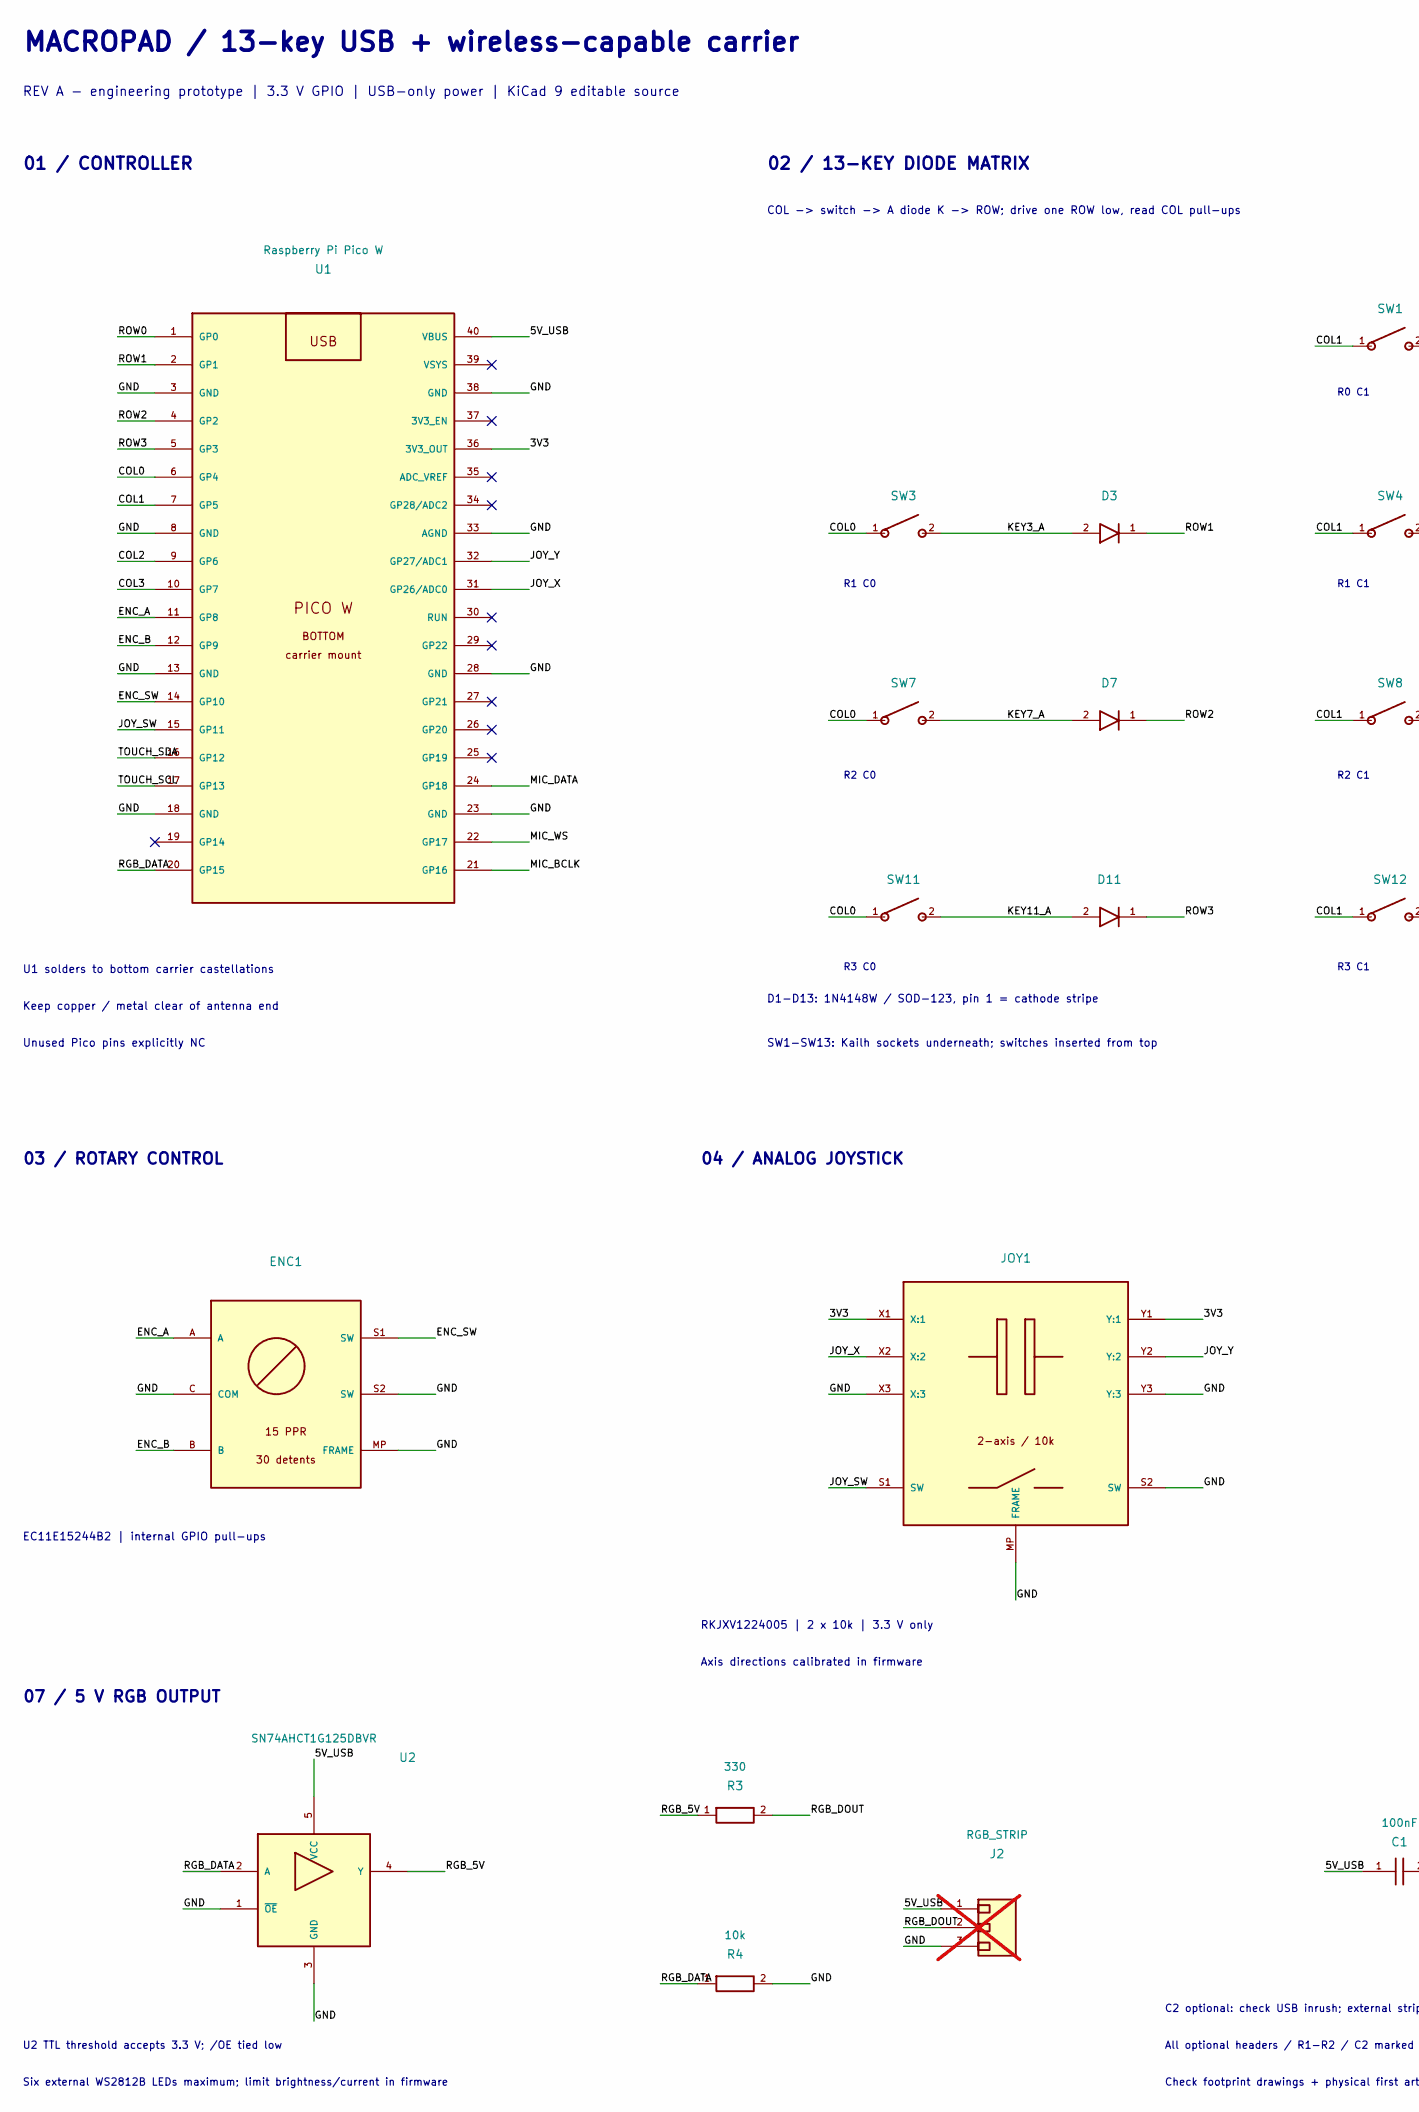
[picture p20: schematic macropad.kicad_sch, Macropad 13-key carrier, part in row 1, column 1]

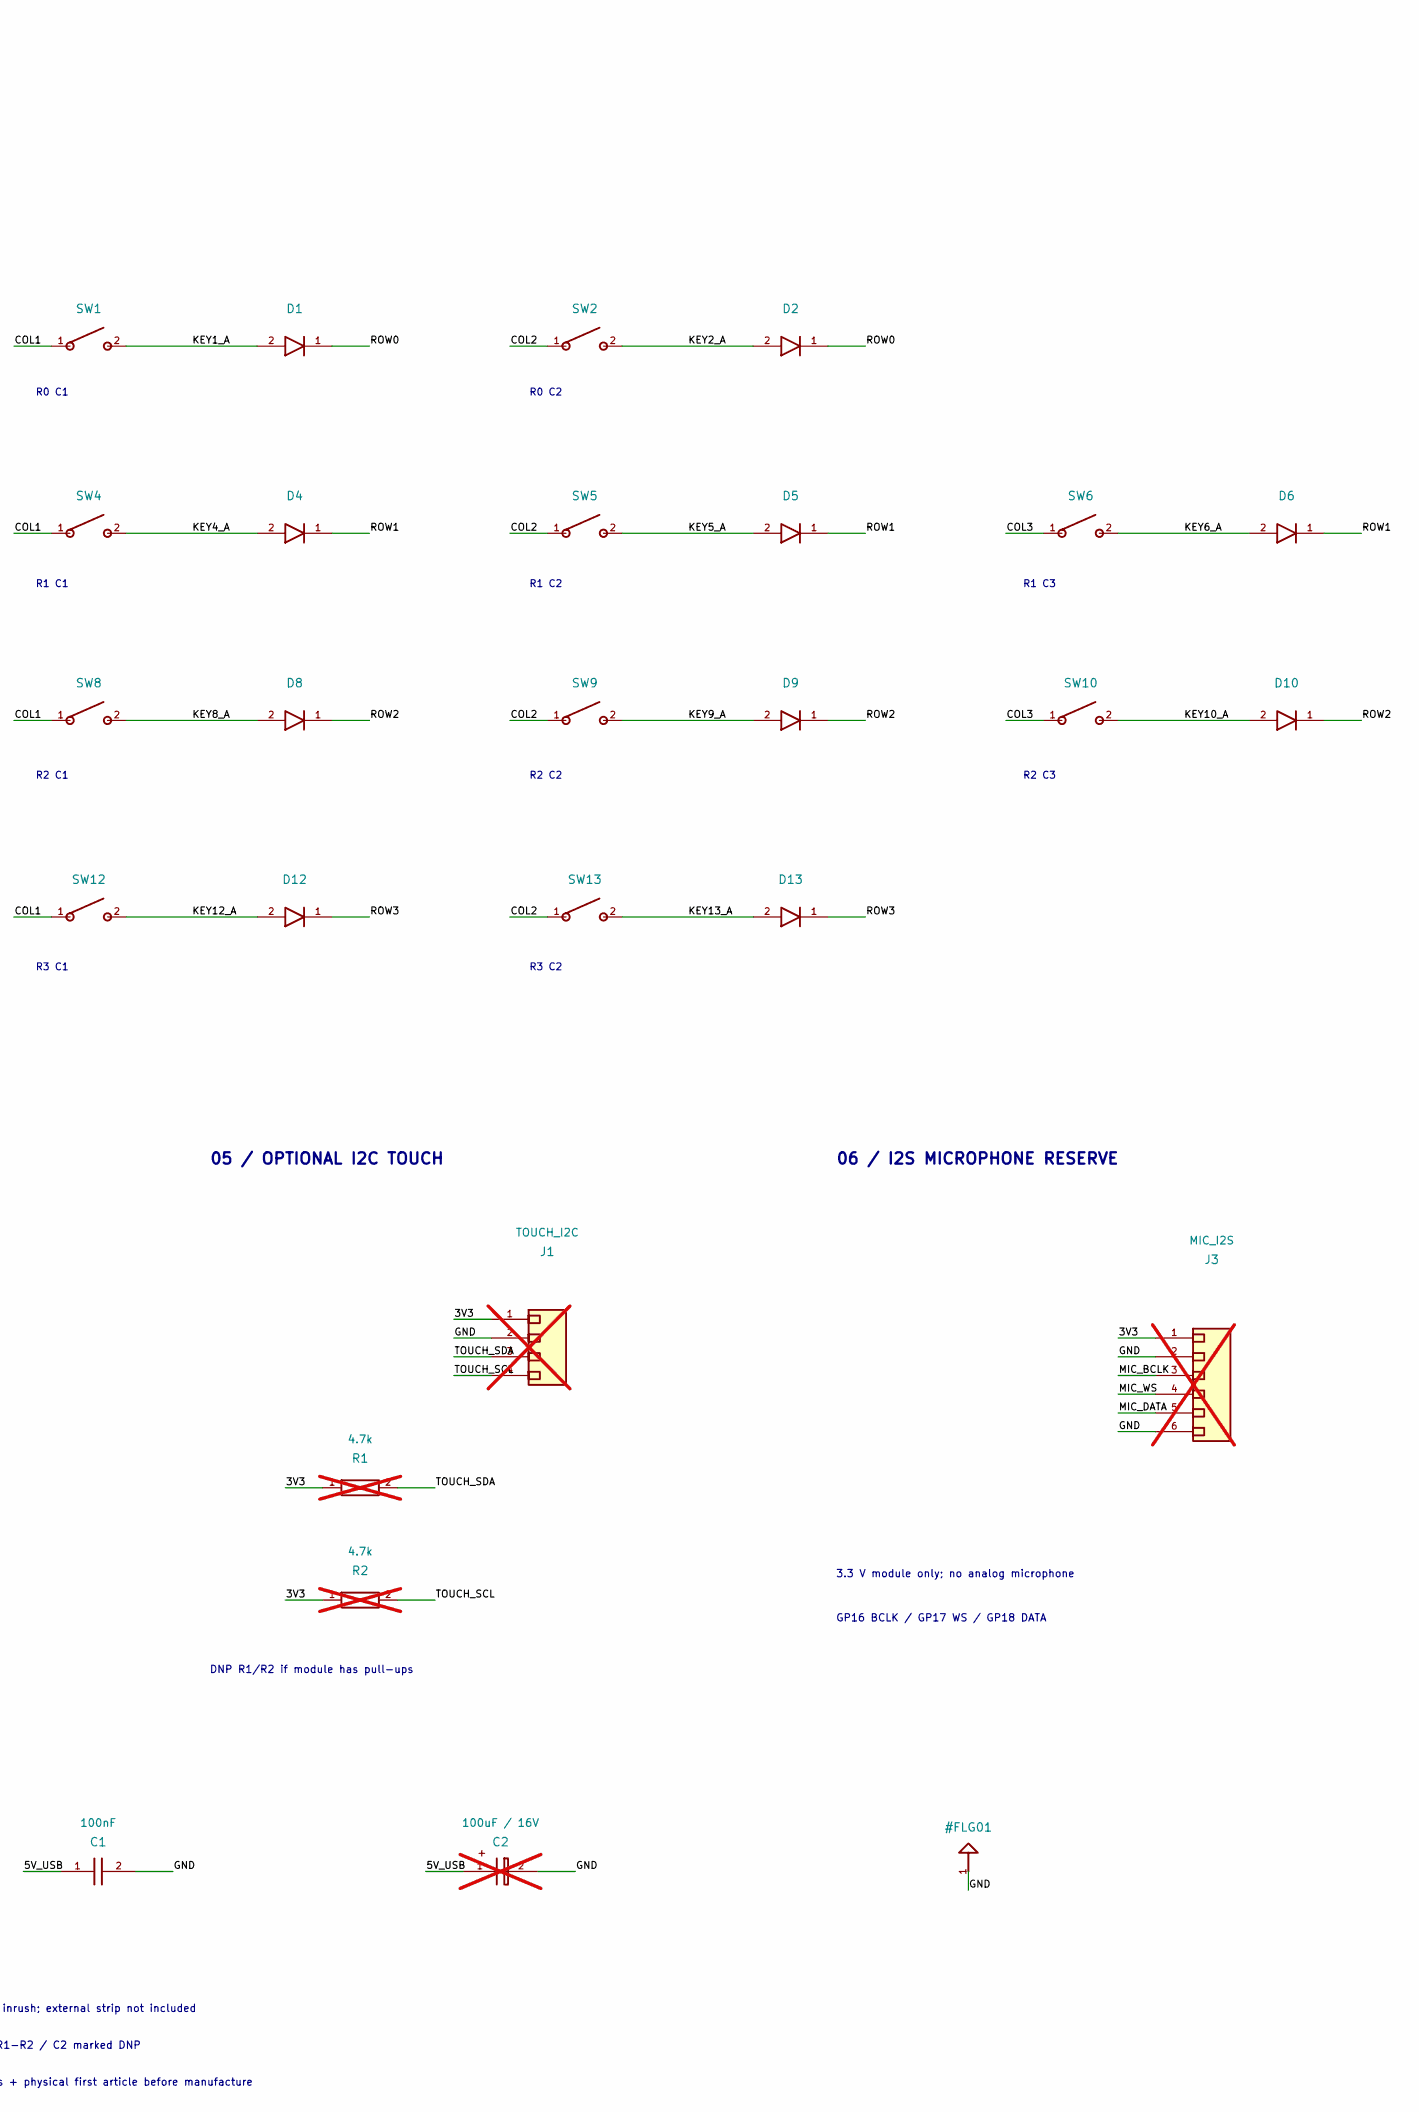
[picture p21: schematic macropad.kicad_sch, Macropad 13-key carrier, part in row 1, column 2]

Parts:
C1: 100nF; C_0603_1608Metric; MPN GRM188R72A104KA35D
C2: 100uF / 16V; CP_Elec_6.3x5.8; MPN EEE-FK1C101P; not fitted
D1, D2, D3, D4, D5, D6, D7, D8, D9, D10, D11, D12, D13: 1N4148W; D_SOD-123; MPN 1N4148W-7-F
ENC1: EC11E15244B2; RotaryEncoder_Alps_EC11E-Switch_Vertical_H20mm; MPN EC11E15244B2
J1: TOUCH_I2C; PinHeader_1x04_P2.54mm_Vertical; MPN TSW-104-07-G-S; not fitted
J2: RGB_STRIP; PinHeader_1x03_P2.54mm_Vertical; MPN TSW-103-07-G-S; not fitted
J3: MIC_I2S; PinHeader_1x06_P2.54mm_Vertical; MPN TSW-106-07-G-S; not fitted
JOY1: RKJXV1224005; Joystick_RKJXV1224005; MPN RKJXV1224005
R1, R2: 4.7k; R_0603_1608Metric; MPN RC0603FR-074K7L; not fitted
R3: 330; R_0603_1608Metric; MPN RC0603FR-07330RL
R4: 10k; R_0603_1608Metric; MPN RC0603FR-0710KL
SW1, SW2, SW3, SW4, SW5, SW6, SW7, SW8, SW9, SW10, SW11, SW12, SW13: MX hot-swap; MX_Hotswap_CPG151101S11_16; MPN CPG151101S11-16
U1: Raspberry Pi Pico W; PicoW_Castellated; MPN SC0918
U2: SN74AHCT1G125DBVR; SOT-23-5; MPN SN74AHCT1G125DBVR

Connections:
/3V3: J1.1, J3.1, JOY1.X1 (X:1), JOY1.Y1 (Y:1), R1.1, R2.1, U1.36 (3V3_OUT)
/5V_USB: C1.1, C2.1 (+), J2.1, U1.40 (VBUS), U2.5 (VCC)
/COL0: SW3.1, SW7.1, SW11.1, U1.6 (GP4)
/COL1: SW1.1, SW4.1, SW8.1, SW12.1, U1.7 (GP5)
/COL2: SW2.1, SW5.1, SW9.1, SW13.1, U1.9 (GP6)
/COL3: SW6.1, SW10.1, U1.10 (GP7)
/ENC_A: ENC1.A, U1.11 (GP8)
/ENC_B: ENC1.B, U1.12 (GP9)
/ENC_SW: ENC1.S1 (SW), U1.14 (GP10)
/GND: C1.2, C2.2 (-), ENC1.C (COM), ENC1.MP (FRAME), ENC1.S2 (SW), J1.2, J2.3, J3.2, J3.6, JOY1.MP (FRAME), JOY1.S2 (SW), JOY1.X3 (X:3), JOY1.Y3 (Y:3), R4.2, U1.3 (GND), U1.8 (GND), U1.13 (GND), U1.18 (GND), U1.23 (GND), U1.28 (GND), U1.33 (AGND), U1.38 (GND), U2.1 (~OE), U2.3 (GND)
/JOY_SW: JOY1.S1 (SW), U1.15 (GP11)
/JOY_X: JOY1.X2 (X:2), U1.31 (GP26/ADC0)
/JOY_Y: JOY1.Y2 (Y:2), U1.32 (GP27/ADC1)
/KEY1_A: D1.2 (A), SW1.2
/KEY2_A: D2.2 (A), SW2.2
/KEY3_A: D3.2 (A), SW3.2
/KEY4_A: D4.2 (A), SW4.2
/KEY5_A: D5.2 (A), SW5.2
/KEY6_A: D6.2 (A), SW6.2
/KEY7_A: D7.2 (A), SW7.2
/KEY8_A: D8.2 (A), SW8.2
/KEY9_A: D9.2 (A), SW9.2
/KEY10_A: D10.2 (A), SW10.2
/KEY11_A: D11.2 (A), SW11.2
/KEY12_A: D12.2 (A), SW12.2
/KEY13_A: D13.2 (A), SW13.2
/MIC_BCLK: J3.3, U1.21 (GP16)
/MIC_DATA: J3.5, U1.24 (GP18)
/MIC_WS: J3.4, U1.22 (GP17)
/RGB_5V: R3.1, U2.4 (Y)
/RGB_DATA: R4.1, U1.20 (GP15), U2.2 (A)
/RGB_DOUT: J2.2, R3.2
/ROW0: D1.1 (K), D2.1 (K), U1.1 (GP0)
/ROW1: D3.1 (K), D4.1 (K), D5.1 (K), D6.1 (K), U1.2 (GP1)
/ROW2: D7.1 (K), D8.1 (K), D9.1 (K), D10.1 (K), U1.4 (GP2)
/ROW3: D11.1 (K), D12.1 (K), D13.1 (K), U1.5 (GP3)
/TOUCH_SCL: J1.4, R2.2, U1.17 (GP13)
/TOUCH_SDA: J1.3, R1.2, U1.16 (GP12)

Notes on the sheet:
MACROPAD / 13-key USB + wireless-capable carrier
REV A - engineering prototype | 3.3 V GPIO | USB-only power | KiCad 9 editable source
01 / CONTROLLER
U1 solders to bottom carrier castellations
Keep copper / metal clear of antenna end
Unused Pico pins explicitly NC
02 / 13-KEY DIODE MATRIX
COL -> switch -> A diode K -> ROW; drive one ROW low, read COL pull-ups
R0 C1
R0 C2
R1 C0
R1 C1
R1 C2
R1 C3
R2 C0
R2 C1
R2 C2
R2 C3
R3 C0
R3 C1
R3 C2
D1-D13: 1N4148W / SOD-123, pin 1 = cathode stripe
SW1-SW13: Kailh sockets underneath; switches inserted from top
03 / ROTARY CONTROL
EC11E15244B2 | internal GPIO pull-ups
04 / ANALOG JOYSTICK
RKJXV1224005 | 2 x 10k | 3.3 V only
Axis directions calibrated in firmware
05 / OPTIONAL I2C TOUCH
DNP R1/R2 if module has pull-ups
06 / I2S MICROPHONE RESERVE
3.3 V module only; no analog microphone
GP16 BCLK / GP17 WS / GP18 DATA
07 / 5 V RGB OUTPUT
U2 TTL threshold accepts 3.3 V; /OE tied low
Six external WS2812B LEDs maximum; limit brightness/current in firmware
C2 optional: check USB inrush; external strip not included
All optional headers / R1-R2 / C2 marked DNP
Check footprint drawings + physical first article before manufacture

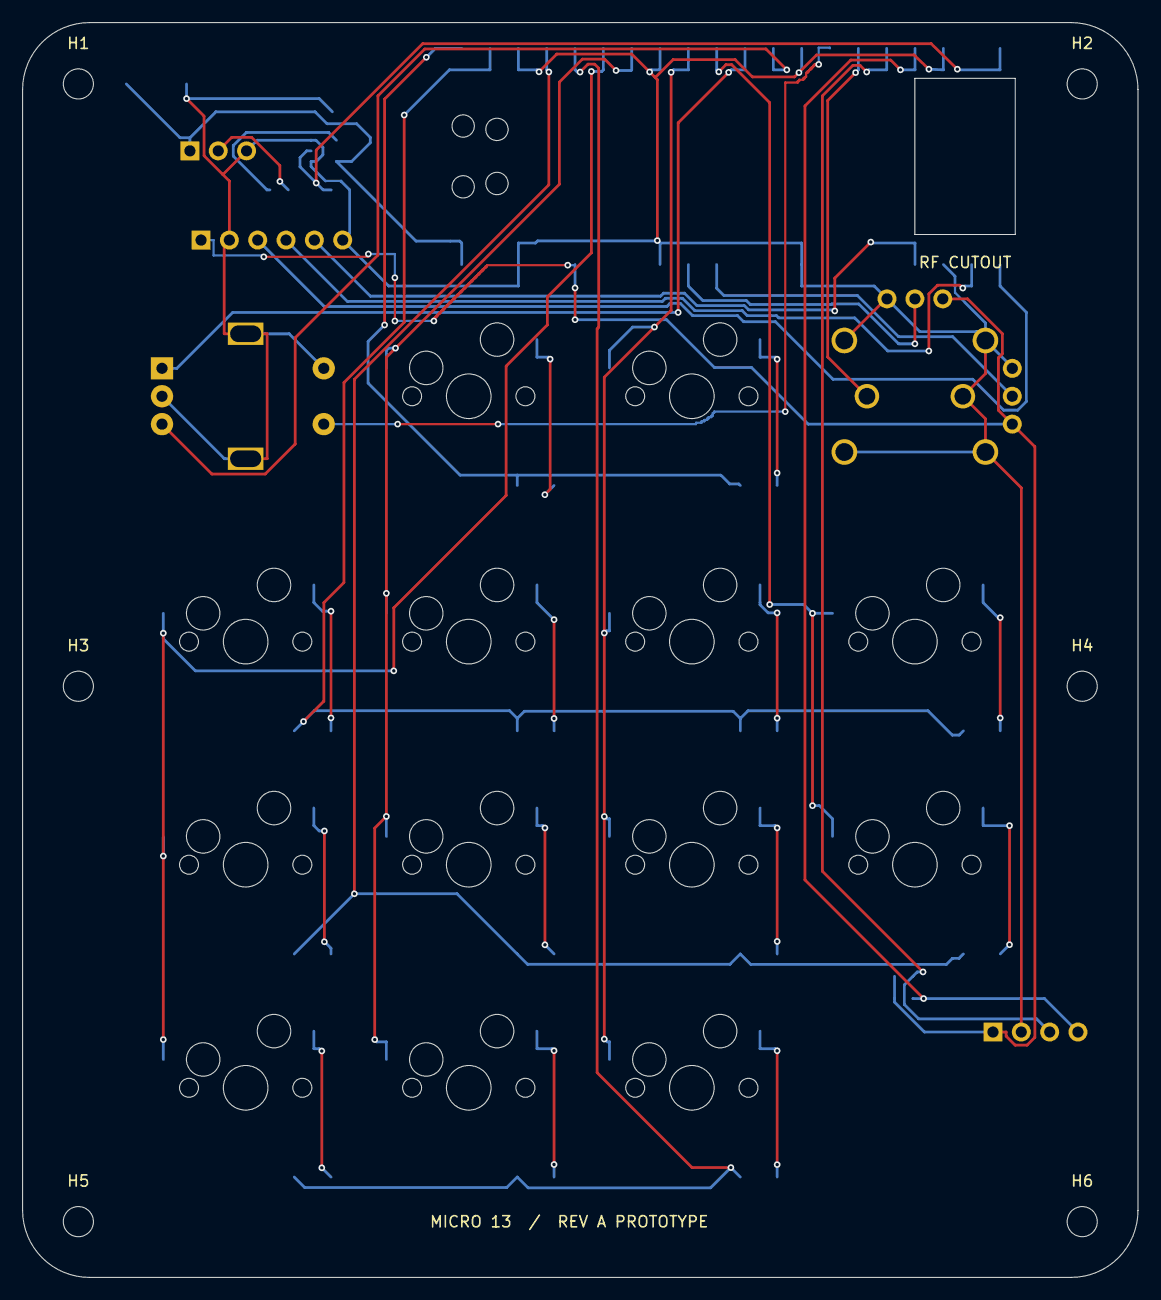
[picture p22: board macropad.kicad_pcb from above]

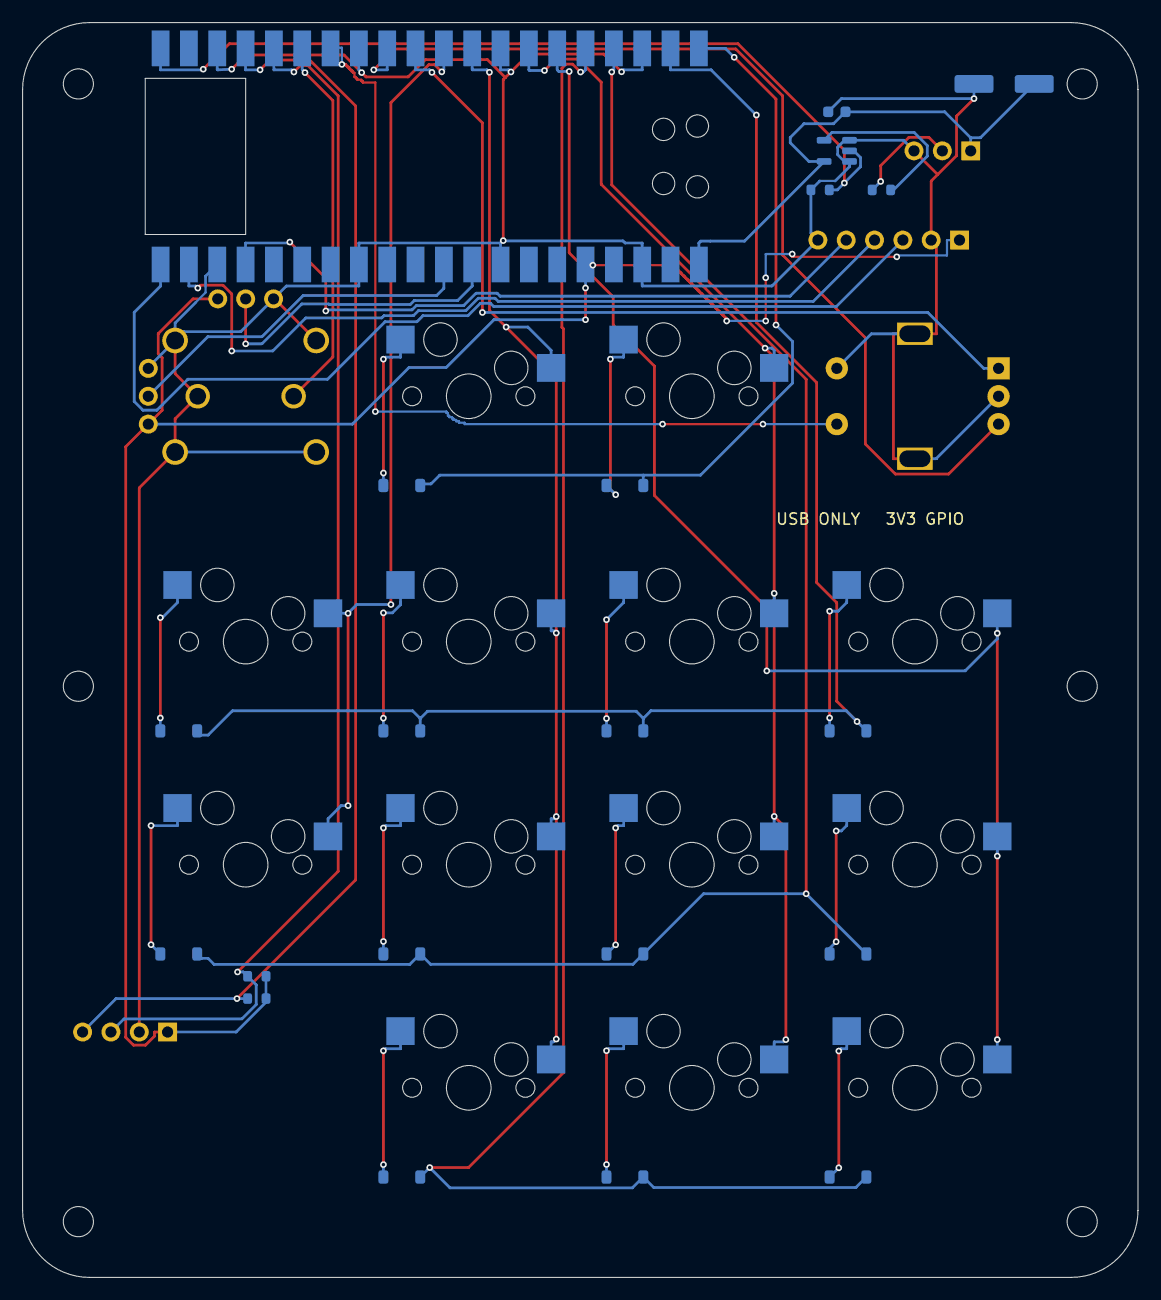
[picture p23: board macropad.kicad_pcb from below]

Board: 2 copper layers, 100.0 x 112.5 mm, 45 parts (34 on the bottom side), 38 nets.

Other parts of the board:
H1, H2, H3, H4, H5, H6: MountingHole_2.7mm_M2.5

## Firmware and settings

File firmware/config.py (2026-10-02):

"""Edit this file on CIRCUITPY. All behavior is code-configured; no GUI."""
from macropad.actions import keys, tap, consumer, wheel, momentary, agent, NONE

# Board connector contract: four row cathodes / four column anodes.
ROW_PINS = ("GP0", "GP1", "GP2", "GP3")
COLUMN_PINS = ("GP4", "GP5", "GP6", "GP7")
COLUMNS_TO_ANODES = True
# K00..K12 in visual reading order. The three absent corners are ignored.
MATRIX_TO_KEY = {1: "K00", 2: "K01", 4: "K02", 5: "K03", 6: "K04",
                 7: "K05", 8: "K06", 9: "K07", 10: "K08", 11: "K09",
                 12: "K10", 13: "K11", 14: "K12"}
ENCODER_A, ENCODER_B = "GP8", "GP9"
ENCODER_CLICK, JOYSTICK_CLICK = "GP10", "GP11"
JOYSTICK_X, JOYSTICK_Y = "GP26", "GP27"
# GP12/13: optional I2C SDA/SCL; GP16/17/18 reserved mic. Not driven here.
SCAN_INTERVAL = 0.005
DEBOUNCE_SCANS = 3
ENCODER_DIVISOR = 4  # adjust for actual encoder detents (typically 4 edges)
ENCODER_INVERTED = False
JOYSTICK_MODE = "arrows"  # "arrows", "mouse", or "disabled"
JOYSTICK_POLL = 0.010
AXIS_X = {"minimum": 0, "center": 32768, "maximum": 65535,
          "enter": 0.35, "leave": 0.22, "inverted": False}
AXIS_Y = {"minimum": 0, "center": 32768, "maximum": 65535,
          "enter": 0.35, "leave": 0.22, "inverted": False}
MOUSE_MAX_STEP = 10
TRANSPORT = "usb"  # "usb" or explicit opt-in "wifi"; never both
TARGET_OS = "windows"  # "windows" / "linux" select CONTROL shortcuts
PRIMARY = "LEFT_GUI" if TARGET_OS == "macos" else "LEFT_CONTROL"

# Base: safe unassigned F13..F24, a held Fn key, media encoder and arrows.
LAYERS = {0: {
    "K00": keys("F13"), "K01": keys("F14"),
    "K02": keys("F15"), "K03": keys("F16"), "K04": keys("F17"), "K05": keys("F18"),
    "K06": keys("F19"), "K07": keys("F20"), "K08": keys("F21"), "K09": keys("F22"),
    "K10": keys("F23"), "K11": keys("F24"), "K12": momentary(1),
    "ENC_CW": consumer("VOLUME_INCREMENT"), "ENC_CCW": consumer("VOLUME_DECREMENT"),
    "ENC_CLICK": consumer("MUTE"), "JOY_CLICK": keys("ENTER"),
    "JOY_LEFT": keys("LEFT_ARROW"), "JOY_RIGHT": keys("RIGHT_ARROW"),
    "JOY_UP": keys("UP_ARROW"), "JOY_DOWN": keys("DOWN_ARROW"),
}, 1: {
    "K00": tap(PRIMARY, "C"), "K01": tap(PRIMARY, "V"),
    "K02": tap(PRIMARY, "X"), "K03": tap(PRIMARY, "Z"),
    "K04": tap(PRIMARY, "LEFT_SHIFT", "Z"), "K05": tap(PRIMARY, "S"),
    "K06": keys("HOME"), "K07": keys("END"),
    "K08": keys("PAGE_UP"), "K09": keys("PAGE_DOWN"),
    "K10": keys("ESCAPE"), "K11": keys("TAB"),
    "ENC_CW": wheel(-1), "ENC_CCW": wheel(1),
}}
# To enable six Microbridge agent keys, replace the bindings you choose:
# for i in range(6): LAYERS[0]["K%02d" % (i + 2)] = agent(i)
# The bridge can focus/open an assigned agent; it cannot approve, reject or type.
COMPANION_ENABLED = False
RGB_ENABLED = False  # six external addressable LEDs; see electrical guide
RGB_PIN = "GP15"
RGB_BRIGHTNESS_LIMIT = 0.15  # hard local power/brightness cap
LED_STALE_SECONDS = 2.0

# Wi-Fi is opt-in: see settings.example.toml and companion/wifi_companion.py.
# USB Microbridge agent/LED integration is separate from Wi-Fi HID mode.
# No BLE HID is implemented on this CircuitPython Pico W target.

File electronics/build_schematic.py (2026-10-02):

from pathlib import Path
import json, uuid, csv
ROOT=Path(__file__).resolve().parents[1]; E=ROOT/'electronics'; L=E/'libraries/symbols'; D=ROOT/'docs'
for p in (E,L,D):p.mkdir(parents=True,exist_ok=True)
U=lambda:str(uuid.uuid4())
components=[]
def comp(ref,value,footprint,pins,**kw):
 c=dict(ref=ref,uuid=str(uuid.uuid5(uuid.NAMESPACE_URL,'macropad:component:'+ref)),value=value,footprint=footprint,pins={str(k):v for k,v in pins.items()},**kw); components.append(c);return c
pico_pins={1:'ROW0',2:'ROW1',3:'GND',4:'ROW2',5:'ROW3',6:'COL0',7:'COL1',8:'GND',9:'COL2',10:'COL3',11:'ENC_A',12:'ENC_B',13:'GND',14:'ENC_SW',15:'JOY_SW',16:'TOUCH_SDA',17:'TOUCH_SCL',18:'GND',19:None,20:'RGB_DATA',21:'MIC_BCLK',22:'MIC_WS',23:'GND',24:'MIC_DATA',25:None,26:None,27:None,28:'GND',29:None,30:None,31:'JOY_X',32:'JOY_Y',33:'GND',34:None,35:None,36:'3V3',37:None,38:'GND',39:None,40:'5V_USB'}
comp('U1','Raspberry Pi Pico W','Macropad:PicoW_Castellated',pico_pins,manufacturer='Raspberry Pi',mpn='SC0918',source='https://datasheets.raspberrypi.com/picow/pico-w-datasheet.pdf',side='B',description='USB-powered Pico W; castellated carrier mount; USB connector faces left edge; antenna faces right')
for i,(r,c) in enumerate([(0,1),(0,2)]+[(1,c)for c in range(4)]+[(2,c)for c in range(4)]+[(3,c)for c in range(3)],1):
 comp('SW'+str(i),'MX hot-swap','Macropad:MX_Hotswap_CPG151101S11_16',{'1':f'COL{c}','2':f'KEY{i}_A'},manufacturer='Kailh',mpn='CPG151101S11-16',source='https://www.kailhswitch.com/Content/upload/pdf/202215927/CPG151101S11-16.pdf',row=r,col=c,side='B',description='Socket on B.Cu; MX switch inserted from F.Cu; socket and switch are distinct BOM items')
 comp('D'+str(i),'1N4148W','Diode_SMD:D_SOD-123',{'1':f'ROW{r}','2':f'KEY{i}_A'},manufacturer='Diodes Incorporated',mpn='1N4148W-7-F',source='https://www.diodes.com/assets/Datasheets/ds12019.pdf',side='B',description='Pin 1 cathode toward row; pin 2 anode toward switch')
comp('ENC1','EC11E15244B2','Rotary_Encoder:RotaryEncoder_Alps_EC11E-Switch_Vertical_H20mm',{'A':'ENC_A','B':'ENC_B','C':'GND','S1':'ENC_SW','S2':'GND','MP':'GND'},manufacturer='Alps Alpine',mpn='EC11E15244B2',source='https://tech.alpsalpine.com/e/products/detail/EC11E15244B2/',side='F',description='30 detents / 15 pulses, 20 mm flat shaft, push switch')
comp('JOY1','RKJXV1224005','Macropad:Joystick_RKJXV1224005',{'X1':'3V3','X2':'JOY_X','X3':'GND','Y1':'3V3','Y2':'JOY_Y','Y3':'GND','S1':'JOY_SW','S2':'GND','MP':'GND'},manufacturer='Alps Alpine',mpn='RKJXV1224005',source='https://tech.alpsalpine.com/e/products/detail/RKJXV1224005/',side='F',description='Bare 2-axis 10k potentiometer joystick with click; custom logical pad names X/Y1..3 map to manufacturer potentiometer terminals 1..3; NRND')
for ref,n,pins,value in [('J1',4,{1:'3V3',2:'GND',3:'TOUCH_SDA',4:'TOUCH_SCL'},'TOUCH_I2C'),('J2',3,{1:'5V_USB',2:'RGB_DOUT',3:'GND'},'RGB_STRIP'),('J3',6,{1:'3V3',2:'GND',3:'MIC_BCLK',4:'MIC_WS',5:'MIC_DATA',6:'GND'},'MIC_I2S')]:
 comp(ref,value,f'Connector_PinHeader_2.54mm:PinHeader_1x0{n}_P2.54mm_Vertical',pins,manufacturer='Samtec',mpn=f'TSW-10{n}-07-G-S',source=f'https://www.samtec.com/products/tsw',side='F',optional=True,description='Optional 2.54 mm header; external peripherals not on PCB')
for ref,val,net1,net2,mpn in [('R1','4.7k','3V3','TOUCH_SDA','RC0603FR-074K7L'),('R2','4.7k','3V3','TOUCH_SCL','RC0603FR-074K7L'),('R3','330','RGB_5V','RGB_DOUT','RC0603FR-07330RL')]:
 comp(ref,val,'Resistor_SMD:R_0603_1608Metric',{'1':net1,'2':net2},manufacturer='Yageo',mpn=mpn,source='https://www.yageo.com/en/PartSearch',side='B',optional=ref!='R3',description='I2C pull-up: DNP if peripheral already fitted with pull-ups' if ref!='R3' else 'RGB data series damping resistor')
comp('U2','SN74AHCT1G125DBVR','Package_TO_SOT_SMD:SOT-23-5',{'1':'GND','2':'RGB_DATA','3':'GND','4':'RGB_5V','5':'5V_USB'},manufacturer='Texas Instruments',mpn='SN74AHCT1G125DBVR',source='https://www.ti.com/lit/ds/symlink/sn74ahct1g125.pdf',side='B',description='5V TTL-input buffer; 3.3V input accepted; /OE grounded')
comp('C1','100nF','Capacitor_SMD:C_0603_1608Metric',{'1':'5V_USB','2':'GND'},manufacturer='Murata',mpn='GRM188R72A104KA35D',source='https://www.murata.com/en-us/products/productdetail?partno=GRM188R71C104KA01%23',side='B',description='100V X7R bypass adjacent to U2')
comp('C2','100uF / 16V','Capacitor_SMD:CP_Elec_6.3x5.8',{'1':'5V_USB','2':'GND'},manufacturer='Panasonic',mpn='EEE-FK1C101P',source='https://industrial.panasonic.com/ww/products/pt/aluminum-cap-smd/models/EEEFK1C101P',side='B',optional=True,description='Optional polarized bulk capacitor near RGB header; validate USB inrush before populating')
comp('R4','10k','Resistor_SMD:R_0603_1608Metric',{'1':'RGB_DATA','2':'GND'},manufacturer='Yageo',mpn='RC0603FR-0710KL',source='https://www.yageo.com/en/PartSearch',side='B',description='Pull-down holds AHCT input low during reset or high-impedance Pico GPIO state')
manifest=dict(schematic_uuid=str(uuid.uuid5(uuid.NAMESPACE_URL,'macropad:schematic')),schema_version=1,project='macropad',kicad_version='9',components=components,nets=sorted({n for c in components for n in c['pins'].values()if n}),notes=['Null pin nets mean explicit no-connect.','Pin names X1/X2/X3 and Y1/Y2/Y3 are custom JOY1 footprint names for each potentiometer terminal 1/2/3.','Matrix direction COL -> SW pin1 -> SW pin2 -> diode pin2/anode -> diode pin1/cathode -> ROW; firmware drive rows low and read columns pull-up.','Pico W mounted on bottom carrier; no battery or charger; USB is sole intended power source.','Optional external modules are connectors only; stock and availability not checked.','74AHCT level shifter 5V output must never reach Pico GPIO.'])
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

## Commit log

2026-10-02 Initialize FIELD 13 private prototype repository
2026-10-02 Publish checked FIELD 13 A0 design prototype
    Include editable KiCad, FreeCAD and Blender sources, STEP/STL parts, visual README, firmware and assembly documentation.
    Prototype validation: ERC/DRC clean, no unconnected nets, 73 valid CAD solids, 42 clearance checks, 23 CAD-to-PCB alignment checks; 41 firmware tests passed and 5 host-dependent tests skipped. Physical fabrication, fit and electrical bring-up remain unverified.
    [BOM.csv, Control_fit_coupon.step, Control_fit_coupon.stl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]
2026-10-02 Stage native populated PCB STEP for reviewed follow-up
    Upload the complete original STEP through GitHub's supported browser upload. The following checkpoint will organize it with the populated-PCB and PCBA/A1 deliverables.
